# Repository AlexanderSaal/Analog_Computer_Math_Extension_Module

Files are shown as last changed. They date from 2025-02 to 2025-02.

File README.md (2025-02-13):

# Analog Computer: Math Extension Module

This repository provides a math extension module for analog computing applications. The module provides two absolute value functions, two square-root functions, and one logarithmic value function (base $10$ and $e$) of the input. Each output features an indicator LED that provides visual feedback proportional to the output value.

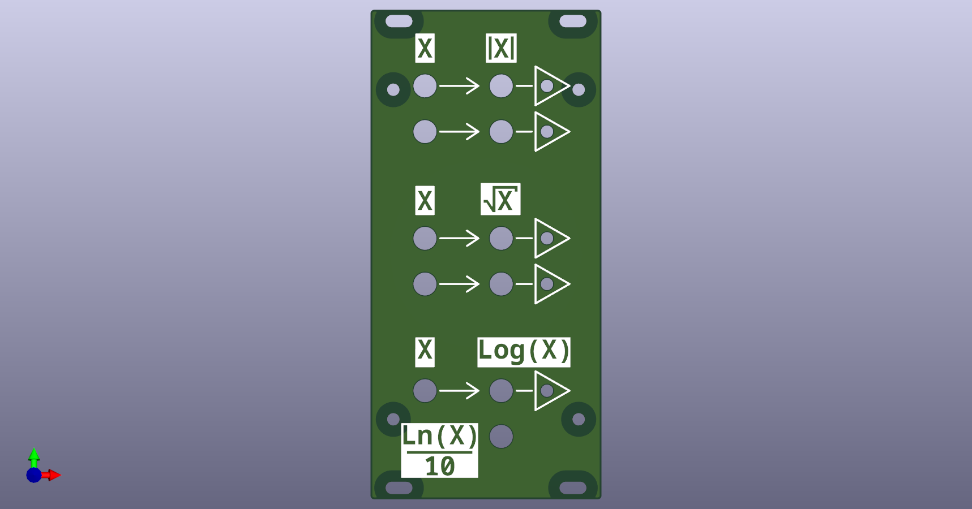
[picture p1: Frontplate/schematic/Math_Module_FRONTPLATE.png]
Front view of the Math Module


## Module Schematic

**<ins>Absolute function(x):</ins>** $x \rightarrow |x|$

The circuit for the absolute value function incorporates two different designs.

The left circuit is based on individual diodes and represents the classical implementation of an absolute value circuit. This circuit follows the design outlined in the document [PRECISION ABSOLUTE VALUE CIRCUITS](https://www.ti.com/lit/pdf/sboa068) from BURR-BROWN/TI.

The right circuit is similar but with one important difference: the diodes are replaced with P-channel MOSFETs on a single substrate. This should ensure thermal coupling and closely specifications of the two MOSFETs.

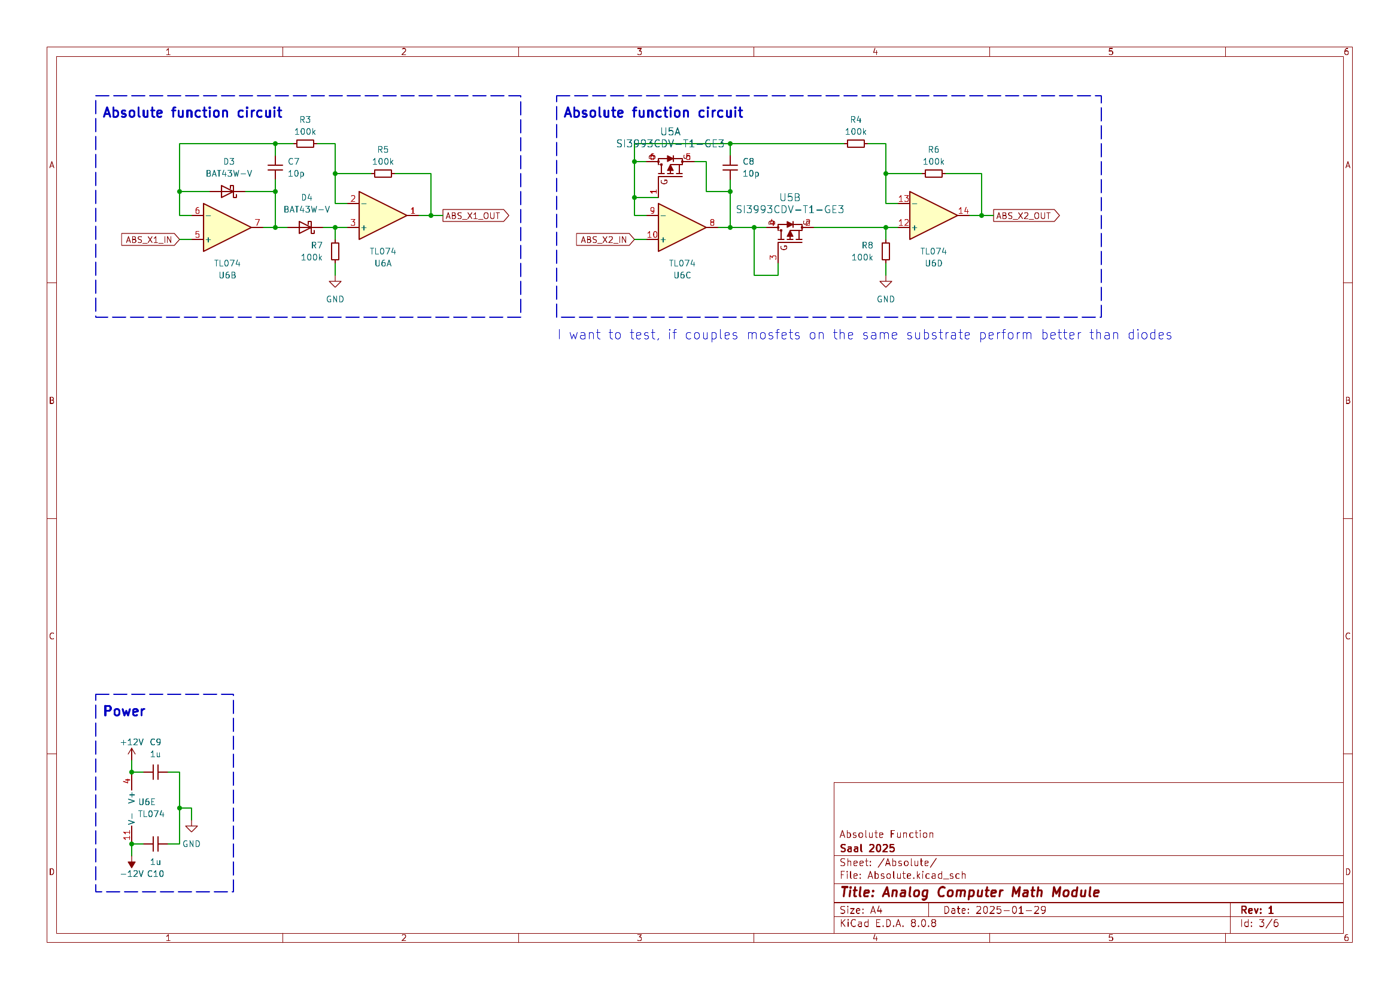
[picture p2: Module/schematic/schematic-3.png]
Schematic of the Absolute function circuit


**<ins>Square-Root function(x):</ins>** $x \rightarrow \sqrt{x}$

The circuit implementation of the square-root function is based on the feedback principle. A multiplier squares the output signal and feeds it back into an open-loop amplifier to yield the inverse function. The diode in the feedback path ensures that only negative values are allowed at the input; otherwise, the output remains close to zero, preventing overload. For ease of use, an inverter is placed before the input, resulting in the overall transfer function of the module:

$$
\begin{align}
  f(x) = \begin{cases}
  \sqrt{x} & \text{if } x > 0 \\
  0 & \text{if } x \le 0
  \end{cases}
\end{align}
$$

This circuit design is based on the schematic and principals presented in the book [Analog and Hybrid Computer Programming](https://www.degruyter.com/document/doi/10.1515/9783110662207/html) by Prof. Dr. Bernd Ulmann and the [book on the THAT Analog Computer](http://www.astro-electronic.de/THAT_Analog_Computer_Book.pdf) by Michael Koch.

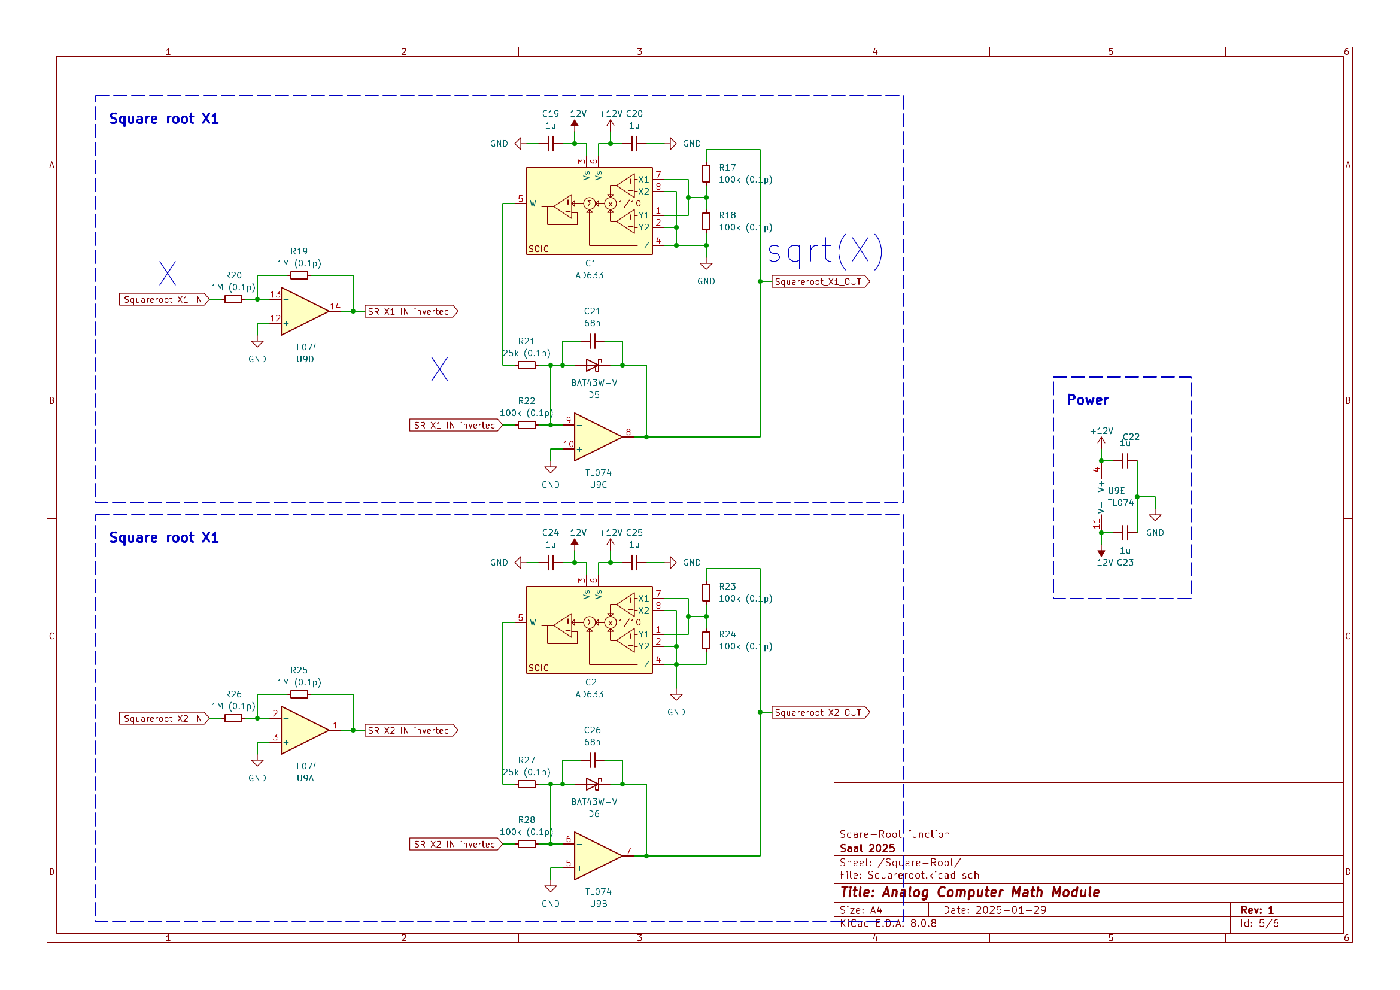
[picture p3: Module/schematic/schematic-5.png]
Schematic of the Square-Root function circuit


**<ins>Logarithmic function(x):</ins>** $x \rightarrow \mathrm{log}_{10}(x)$ and $x \rightarrow \mathrm{log}_{e}(x)$

The logarithm function circuit is based on the [LOG200](https://www.ti.com/product/LOG200) chip from Texas Instruments. The input voltage must be scaled down from $\pm 10 \, V$ to the chip's maximum accepted range of $\pm 5 \, V$. According to the datasheet, $-5V$ falls within the absolute maximum ratings and will not damage the chip.

The transfer function of the LOG200 chip is

$$ V_\mathrm{LOG} = 250 \, mV \cdot \mathrm{log}_{10} \left( \frac{I_1}{I_2} \right) $$

which depends on the ratio of the input currents $I_1$ and $I_2$. The input current $I_2$ is wired to the internal $1 \, \mu A$ precision current source. Accordingly, the input voltage has to be scaled using a precision (0.05\%) $50k\Omega$ resistor to give the appropriate current $I_1$. Since we want to map the output to the full range of our machine unit, $\pm1$ or $\pm 10 \,V$, a "20x" amplifier is placed after the output of the Voltage $V_\mathrm{LOG}$.

With this scaling, the following input-output relationship is achieved:

| Input | Current $I_1$ | Output of LOG200 | Circuit Output |
|---|---|---|---|
|$0.001 \, V$|$0.01 \, \mu A$|$-0.5\,V$ | $-10 \, V$ |
|$0.01 \, V$ |$0.1 \, \mu A$ |$-0.25\,V$ | $-5 \, V$ |
|$0.1 \, V$  |$1 \, \mu A$ |$0\,V$ | $0 \, V$ |
|$1 \, V$ |$10 \, \mu A$  |$0.25\,V$ | $5 \, V$ |
|$10 \, V$ |$100 \, \mu A$ |$0.5\,V$ | $10 \, V$ |

To additionally compute the natural logarithm $\mathrm{log}_e$, we use the relation:

$$ \mathrm{log}_{e}(x) = \frac{\mathrm{log}_{10}(x)}{\mathrm{log}_{10}(e)} = 2.303 \cdot \mathrm{log}_{10}(x) $$

A simple scaling amplifier with a gain of $0.2303x$ is used to provide the output of $\mathrm{log}_e(x) / 10$.

This circuit design and Input/Output scaling are based on the circuit presented in the book [Analog and Hybrid Computer Programming](https://www.degruyter.com/document/doi/10.1515/9783110662207/html) by Prof. Dr. Bernd Ulmann. I took the liberty of replacing the LOG112 with the LOG200 chip and adding the natural logarithm functionality.

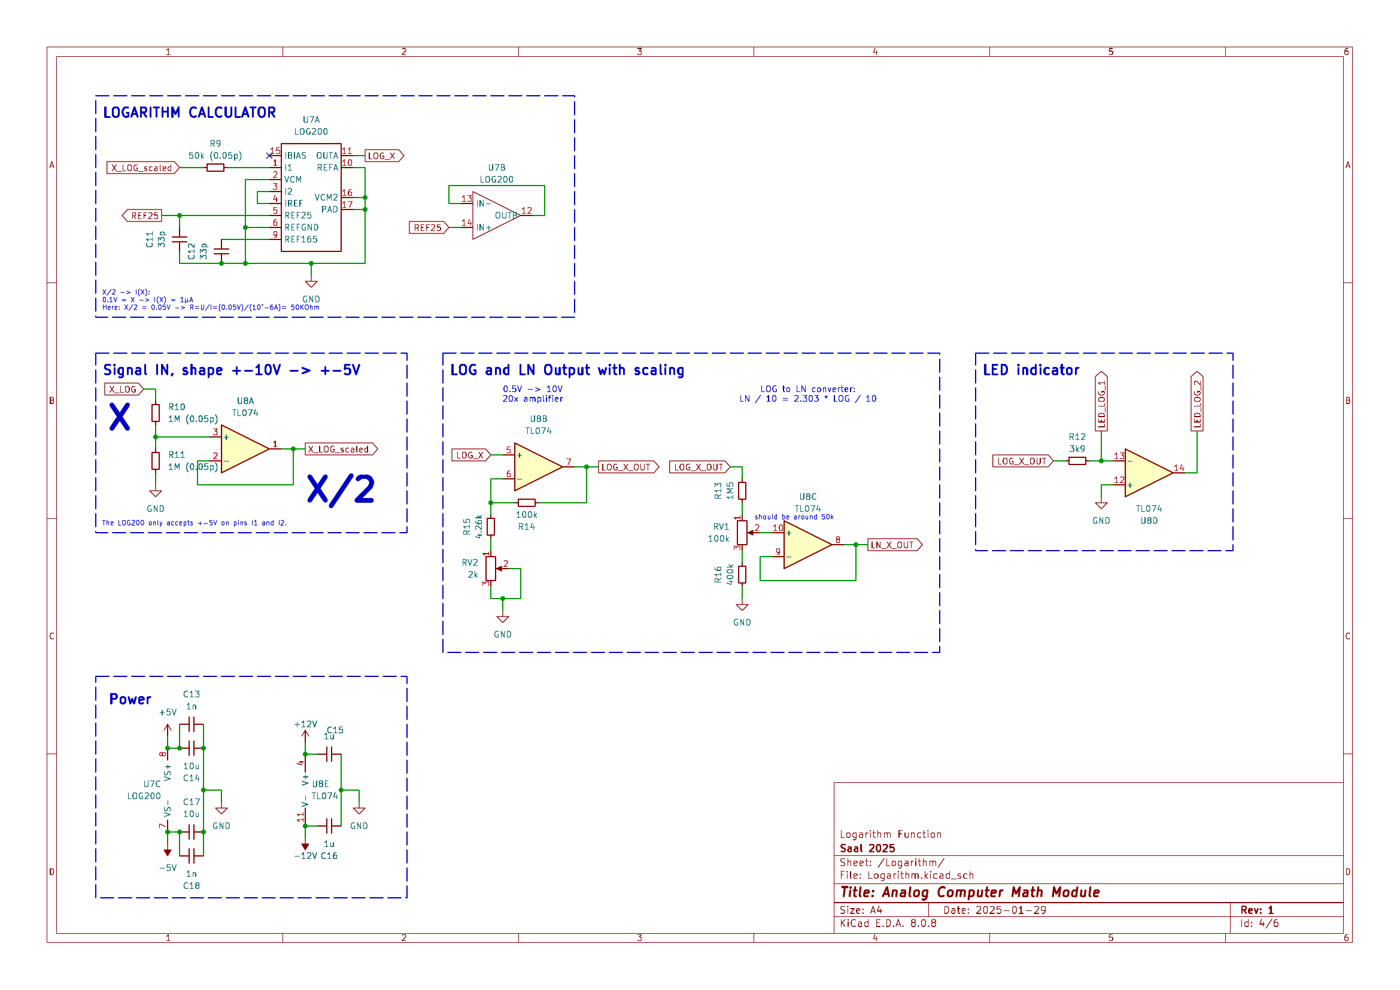
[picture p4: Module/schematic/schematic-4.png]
Schematic of the Logarithm function circuit


## BOM

**<ins>Main Module:</ins>** 

|Reference |Value |Footprint |QUANTITY|
|---|---|---|---|
|C1,C2,C14,C17 |10u |1206 / 3216Metric |4 |
|C3,C5 |0.33u |1206 / 3216Metric |2 |
|C4,C6,C9,C10,C15,C16,C19,C20,C22-C25,C27,C28|1u |1206 / 3216Metric |14 |
|C7,C8 |10p |1206 / 3216Metric |2 |
|C11,C12 |33p |1206 / 3216Metric |2 |
|C13,C18 |1n |1206 / 3216Metric |2 |
|C21,C26 |68p |1206 / 3216Metric |2 |
|D1 |12V_GREEN |1206 / 3216Metric |1 |
|D2 |-12V_RED |1206 / 3216Metric |1 |
|D3-D6 |BAT43W-V |1206 / 3216Metric |4 |
|IC1,IC2 |AD633 |SOIC-8 |2 |
|J1 |Conn_01x23_Pin |PinHeader_1x23_P2.54mm_Vertical |1 |
|J2 |Conn_02x05_Odd_Even|PinHeader_2x05_P2.54mm_Vertical |1 |
|Q1 |PMV250EPEA |SOT-23 |1 |
|Q2 |PMV450ENEA |SOT-23 |1 |
|R1 |11k2 |1206 / 3216Metric |1 |
|R2 |5k6 |1206 / 3216Metric |1 |
|R3-R8,R14 |100k |1206 / 3216Metric |7 |
|R9 |50k (0.05p) |1206 / 3216Metric |1 |
|R10,R11 |1M (0.05p) |1206 / 3216Metric |2 |
|R12,R29-R32 |3k9 |1206 / 3216Metric |5 |
|R13 |1M5 |1206 / 3216Metric |1 |
|R15 |4.26k |1206 / 3216Metric |1 |
|R16 |400k |1206 / 3216Metric |1 |
|R17,R18,R22-R24,R28 |100k (0.1p) |1206 / 3216Metric |6 |
|R19,R20,R25,R26 |1M (0.1p) |1206 / 3216Metric |4 |
|R21,R27 |25k (0.1p) |1206 / 3216Metric |2 |
|RV1 |100k |Potentiometer_Bourns_3296W_Vertical|1 |
|RV2 |2k |Potentiometer_Bourns_3296W_Vertical|1 |
|U1 |MC7805ACTG |TO-220-3_Vertical |1 |
|U2 |MC7905BTG |TO-220-3_Vertical |1 |
|U3,U4 |VCAN16A2 |VCAN16A2-03S-E3-08 |2 |
|U5 |SI3993CDV-T1-GE3 |TSOT-23-6 |1 |
|U6,U8-U10 |TLE2074IDWR |SOIC-14\_3.9x8.7mm\_P1.27mm |4 |
|U7 |LOG200 |VQFN-16 |1 |

**<ins>Middleplate:</ins>**

|Reference |Value |Footprint |QUANTITY|
|---|---|---|---|
|D1-D5 |BI color LED |LED_D3.0mm_FlatTop |5 |
|J1 |Conn_01x23_Pin |PinSocket_1x23_P2.54mm_Vertical |1 |
|U1-U6 |VCAN16A2 |VCAN16A2-03S-E3-08 |6 |

## List of special Components:

- OP-amp: [TLE2074IDWR](https://www.digikey.de/en/products/detail/texas-instruments/TLE2074IDWR/2799317) (Upgrade of the [TL074HIDR](https://www.digikey.de/en/products/detail/texas-instruments/TL074HIDR/13563033))
- logarithmic amplifier: [TL441CN](https://www.digikey.de/de/products/detail/texas-instruments/TL441CN/1675117), [LOG112AID](https://www.digikey.de/de/products/detail/texas-instruments/LOG112AID/486371), [LOG200RGTT](https://www.digikey.de/de/products/detail/texas-instruments/LOG200RGTT/25821029), [LOG200-datasheet](https://www.ti.com/product/LOG200)
- Multiplier: [AD633JRZ](https://www.digikey.de/en/products/detail/analog-devices-inc/AD633JRZ/617831) to [AD835ARZ](https://www.digikey.de/en/products/detail/analog-devices-inc/AD835ARZ-REEL7/621103)
- P-MOSFET: [SSFQ3805](https://www.digikey.de/en/products/detail/good-ark-semiconductor/SSFQ3805/18667583), [SI3993CDV-T1-GE3](https://www.digikey.de/en/products/detail/vishay-siliconix/SI3993CDV-T1-GE3/4876436)
- P-MOSFET (matched pair):[ALD1117SAL](https://www.digikey.de/en/products/detail/advanced-linear-devices-inc/ALD1117SAL/2414325)
- 16-BIT Schottky Barrier Diode Bus-Termination Array: [SN74S1053PWR](https://www.digikey.de/en/products/detail/texas-instruments/SN74S1053PWR/509741)
- 2 PNP (Dual) Matched Pair:[site](https://www.diodes.com/products/discrete-semiconductors/bipolar-transistors/transistor-bjt-master-table/matchedpair/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), [DMMT3906W-7-F](https://www.digikey.de/en/products/detail/diodes-incorporated/DMMT3906W-7-F/717760), [BCM847BS](https://www.digikey.de/en/products/detail/diotec-semiconductor/BCM847BS/22600802)
- +5V Regulator: [MC7805ACTG](https://www.digikey.de/en/products/detail/onsemi/MC7805ACTG/1481210), [MC7805ABTG](https://www.digikey.de/en/products/detail/onsemi/MC7805ABTG/921035)
- -5V Regulator: [MC7905BTG](https://www.digikey.de/en/products/detail/onsemi/MC7905BTG/1481513)

## License

This work is published under the [CERN Open Hardware Licence Version 2 - Strongly Reciprocal](LICENSE)

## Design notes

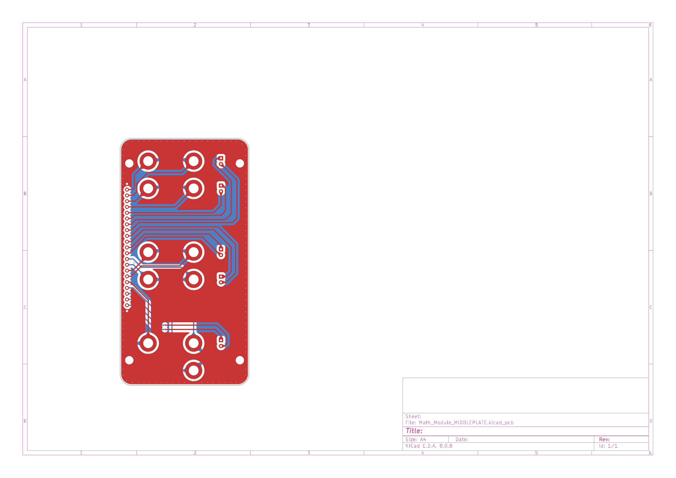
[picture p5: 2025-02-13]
Middleplate/schematic/PCB-1.png

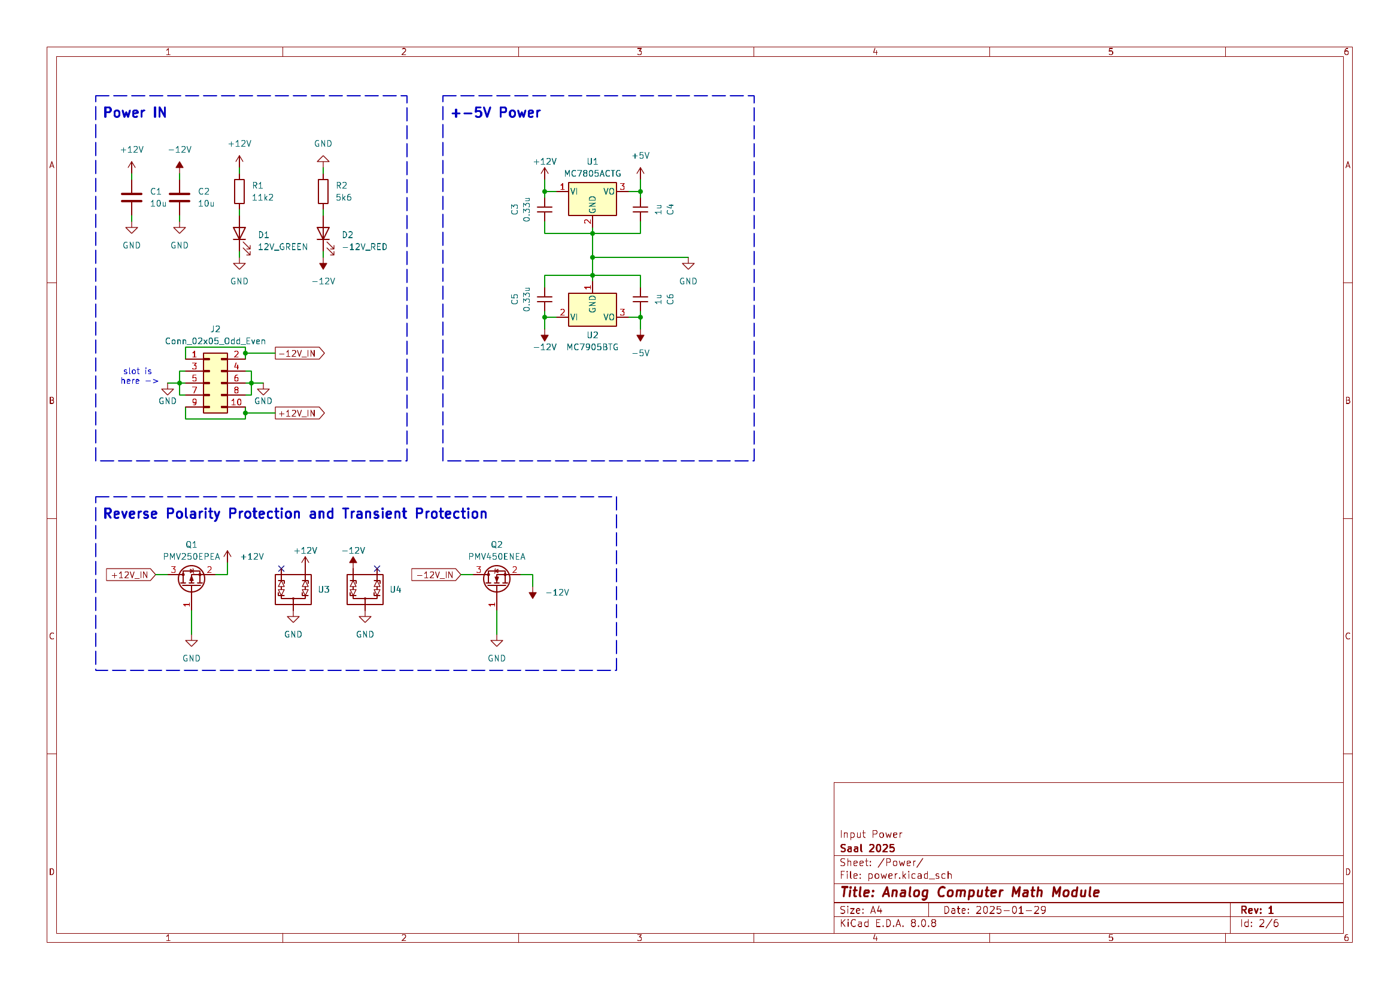
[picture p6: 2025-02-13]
Module/schematic/schematic-2.png

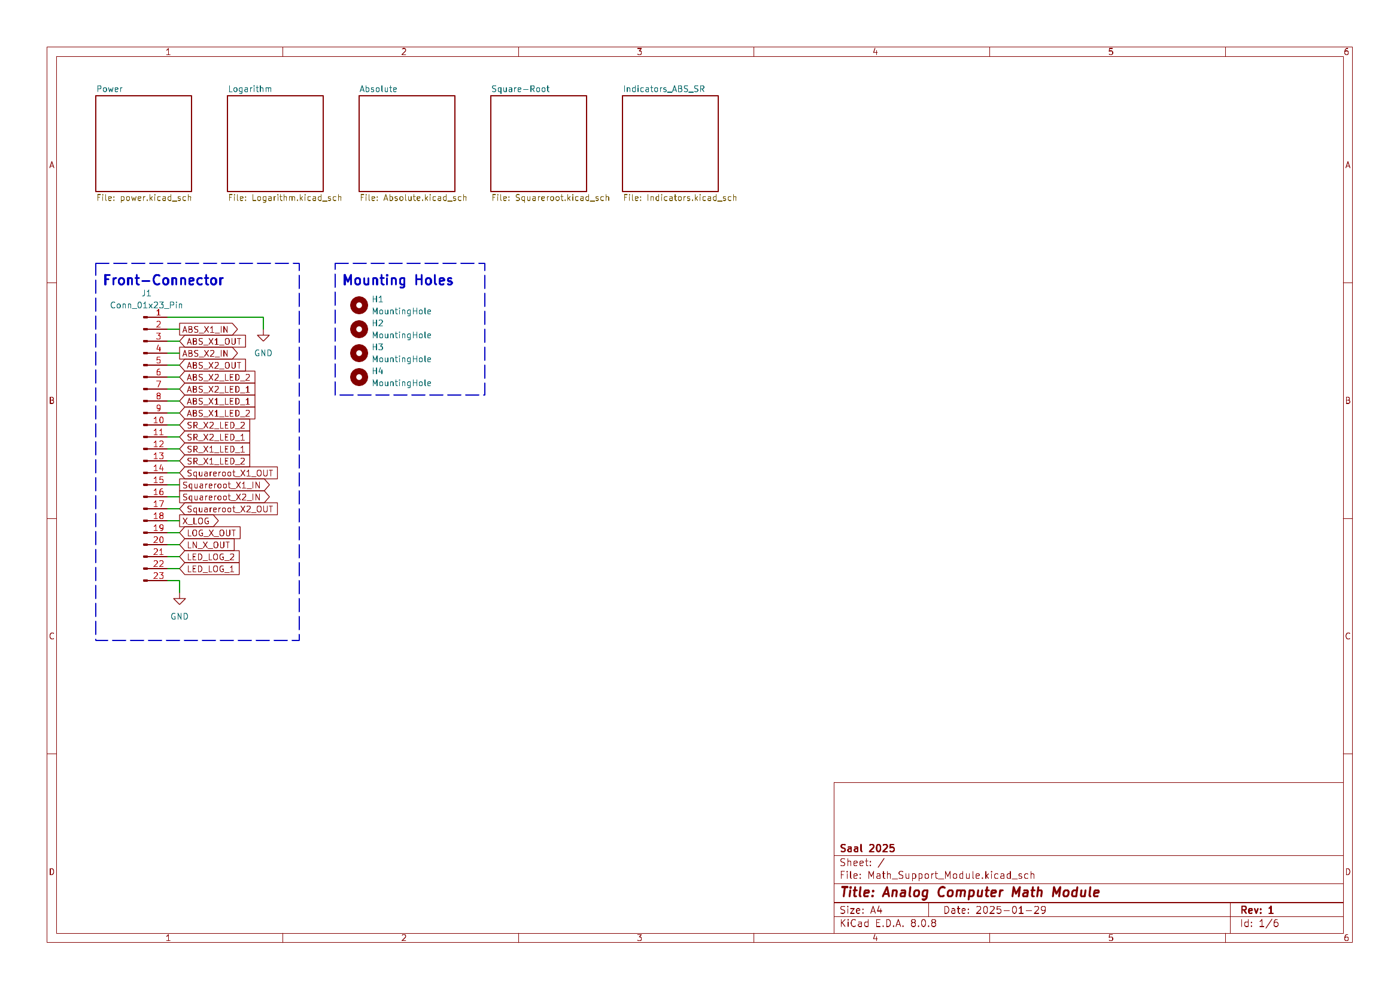
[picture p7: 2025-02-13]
Module/schematic/schematic-1.png

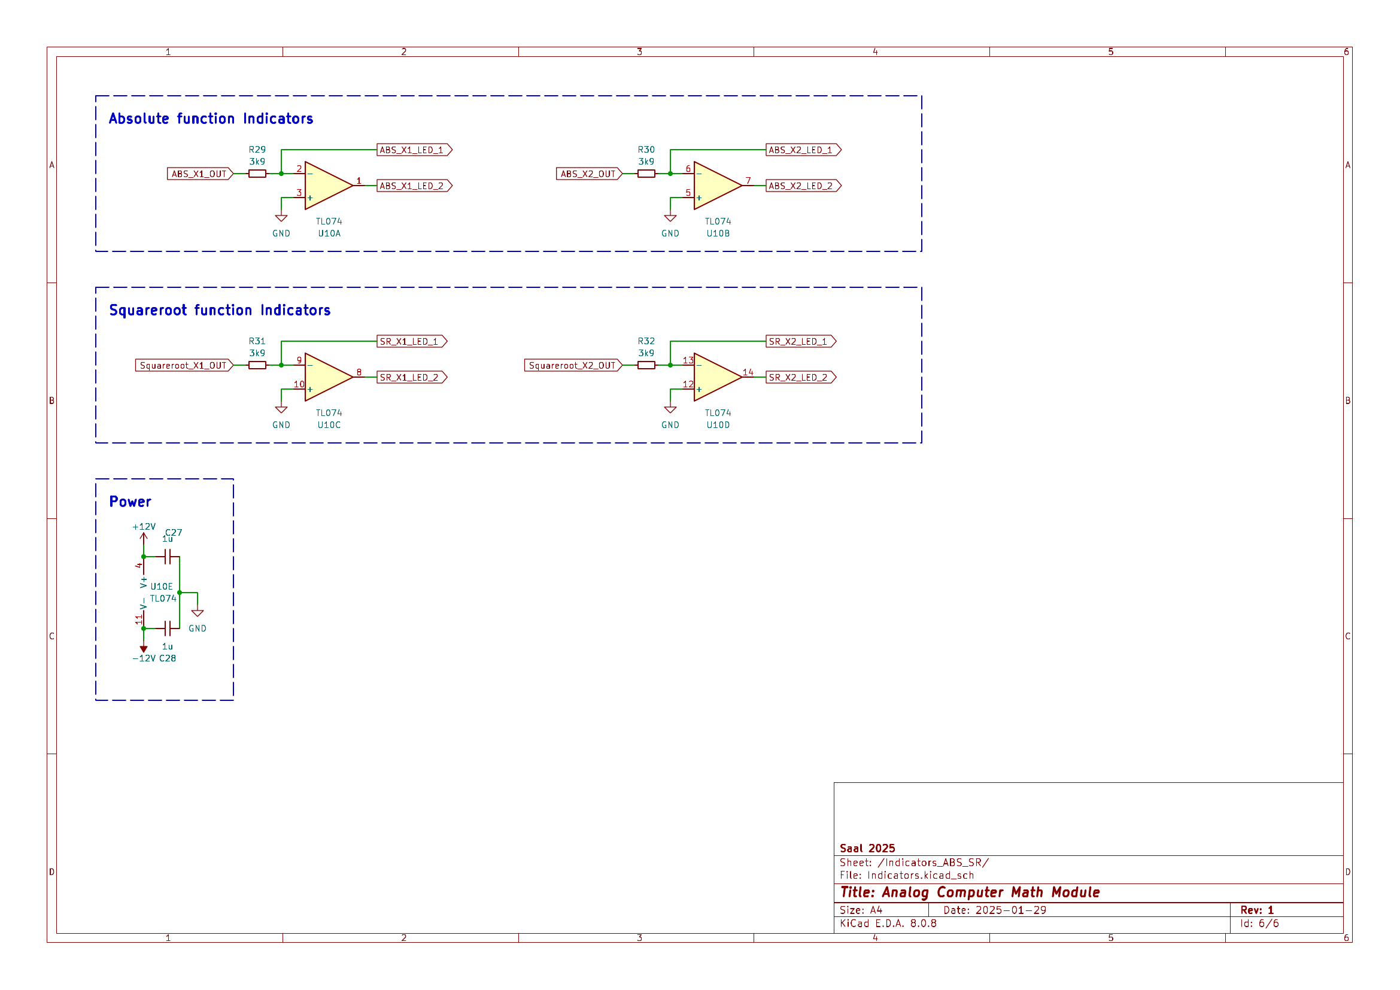
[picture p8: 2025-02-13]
Module/schematic/schematic-6.png

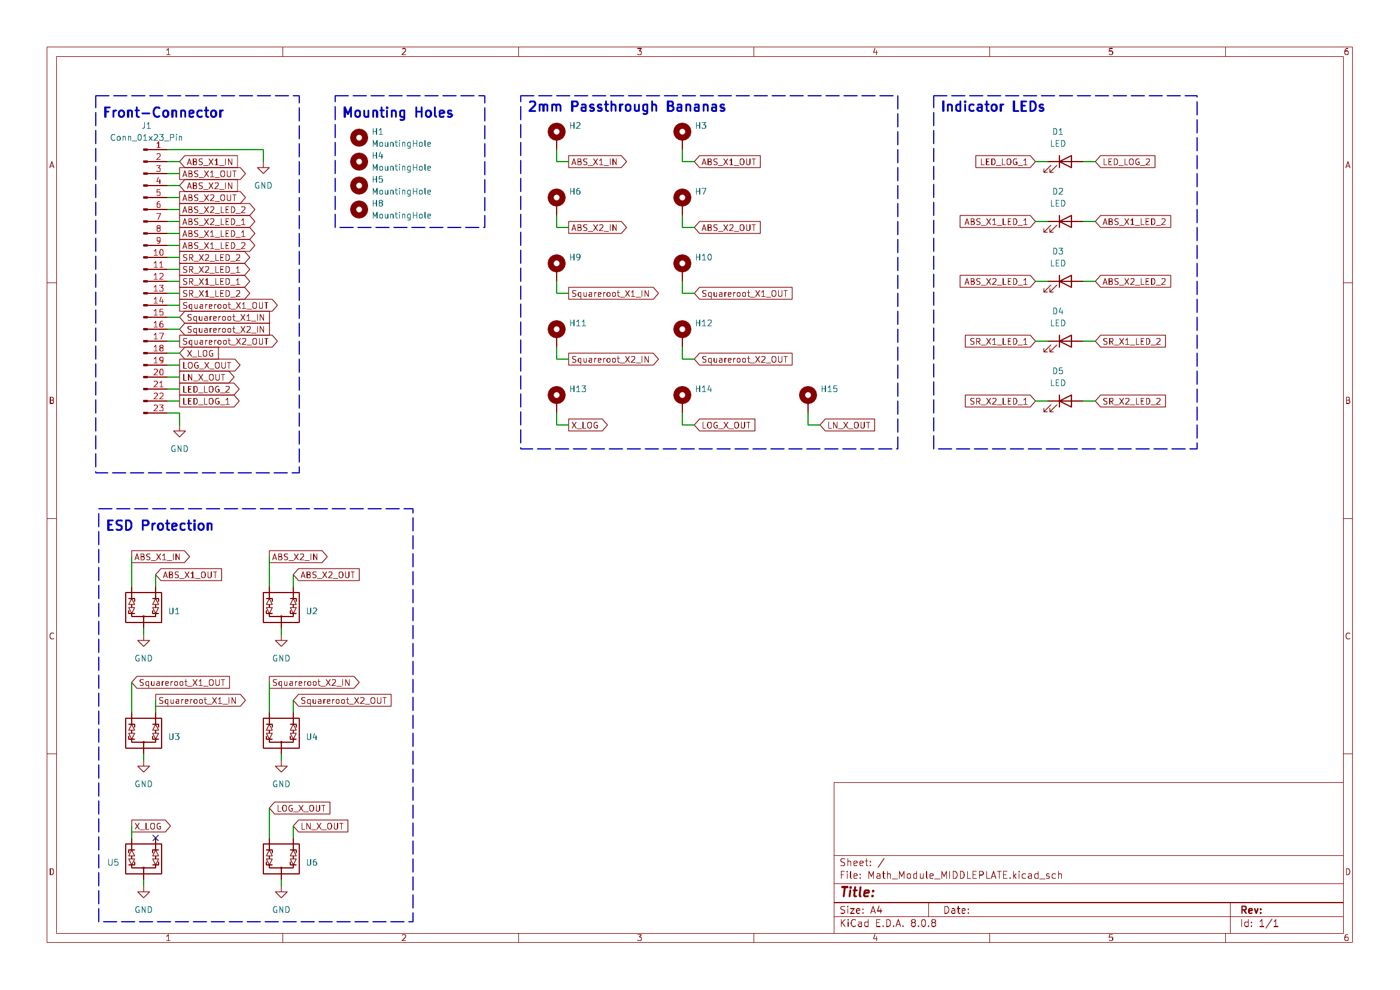
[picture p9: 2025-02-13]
Middleplate/schematic/schematic-1.png

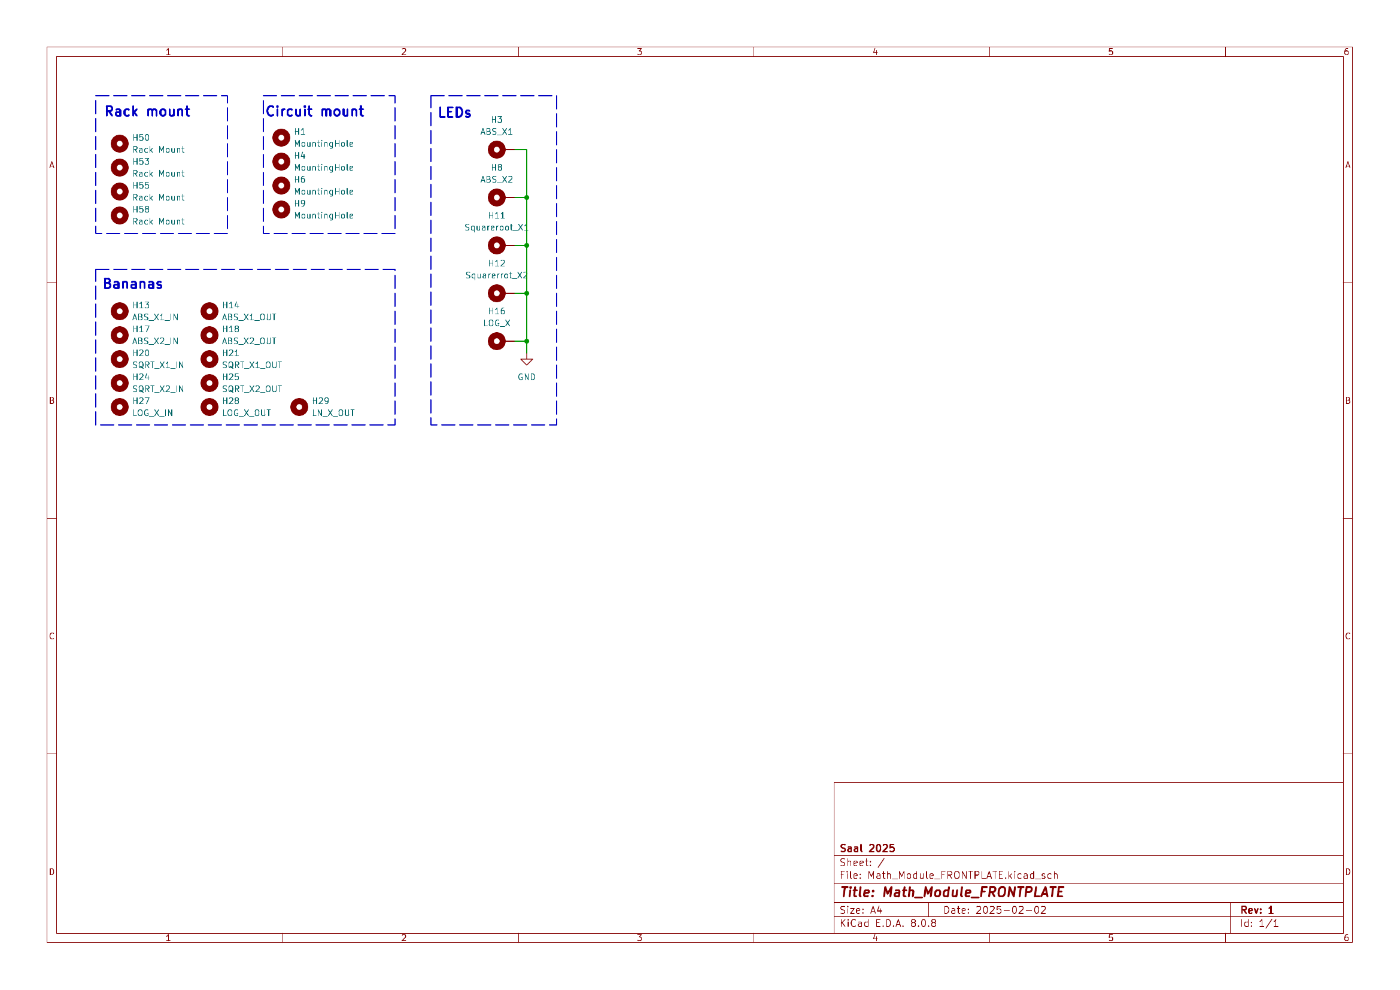
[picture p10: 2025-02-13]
Frontplate/schematic/schematic-1.png

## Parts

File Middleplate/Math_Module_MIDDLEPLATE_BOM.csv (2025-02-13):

Reference | Value | Footprint | QUANTITY
D1-D5 | LED | LED_THT:LED_D3.0mm_FlatTop | 5
J1 | Conn_01x23_Pin | Connector_PinSocket_2.54mm:PinSocket_1x23_P2.54mm_Vertical | 1
U1-U6 | VCAN16A2 | analog_computing:VCAN16A2-03S-E3-08 | 6

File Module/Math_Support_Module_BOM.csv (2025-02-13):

Reference | Value | Footprint | QUANTITY
C1,C2,C14,C17 | 10u | Capacitor_SMD:C_1206_3216Metric_Pad1.33x1.80mm_HandSolder | 4
C3,C5 | 0.33u | Capacitor_SMD:C_1206_3216Metric_Pad1.33x1.80mm_HandSolder | 2
C4,C6,C9,C10,C15,C16,C19,C20,C22-C25,C27,C28 | 1u | Capacitor_SMD:C_1206_3216Metric_Pad1.33x1.80mm_HandSolder | 14
C7,C8 | 10p | Capacitor_SMD:C_1206_3216Metric_Pad1.33x1.80mm_HandSolder | 2
C11,C12 | 33p | Capacitor_SMD:C_1206_3216Metric_Pad1.33x1.80mm_HandSolder | 2
C13,C18 | 1n | Capacitor_SMD:C_1206_3216Metric_Pad1.33x1.80mm_HandSolder | 2
C21,C26 | 68p | Capacitor_SMD:C_1206_3216Metric_Pad1.33x1.80mm_HandSolder | 2
D1 | 12V_GREEN | LED_SMD:LED_1206_3216Metric | 1
D2 | -12V_RED | LED_SMD:LED_1206_3216Metric | 1
D3-D6 | BAT43W-V | Diode_SMD:D_1206_3216Metric_Pad1.42x1.75mm_HandSolder | 4
IC1,IC2 | AD633 | Package_SO:SOIC-8_3.9x4.9mm_P1.27mm | 2
J1 | Conn_01x23_Pin | Connector_PinHeader_2.54mm:PinHeader_1x23_P2.54mm_Vertical | 1
J2 | Conn_02x05_Odd_Even | Connector_PinHeader_2.54mm:PinHeader_2x05_P2.54mm_Vertical | 1
Q1 | PMV250EPEA | Package_TO_SOT_SMD:SOT-23_Handsoldering | 1
Q2 | PMV450ENEA | Package_TO_SOT_SMD:SOT-23_Handsoldering | 1
R1 | 11k2 | Resistor_SMD:R_1206_3216Metric_Pad1.30x1.75mm_HandSolder | 1
R2 | 5k6 | Resistor_SMD:R_1206_3216Metric_Pad1.30x1.75mm_HandSolder | 1
R3-R8,R14 | 100k | Resistor_SMD:R_1206_3216Metric_Pad1.30x1.75mm_HandSolder | 7
R9 | 50k (0.05p) | Resistor_SMD:R_1206_3216Metric_Pad1.30x1.75mm_HandSolder | 1
R10,R11 | 1M (0.05p) | Resistor_SMD:R_1206_3216Metric_Pad1.30x1.75mm_HandSolder | 2
R12,R29-R32 | 3k9 | Resistor_SMD:R_1206_3216Metric_Pad1.30x1.75mm_HandSolder | 5
R13 | 1M5 | Resistor_SMD:R_1206_3216Metric_Pad1.30x1.75mm_HandSolder | 1
R15 | 4.26k | Resistor_SMD:R_1206_3216Metric_Pad1.30x1.75mm_HandSolder | 1
R16 | 400k | Resistor_SMD:R_1206_3216Metric_Pad1.30x1.75mm_HandSolder | 1
R17,R18,R22-R24,R28 | 100k (0.1p) | Resistor_SMD:R_1206_3216Metric_Pad1.30x1.75mm_HandSolder | 6
R19,R20,R25,R26 | 1M (0.1p) | Resistor_SMD:R_1206_3216Metric_Pad1.30x1.75mm_HandSolder | 4
R21,R27 | 25k (0.1p) | Resistor_SMD:R_1206_3216Metric_Pad1.30x1.75mm_HandSolder | 2
RV1 | 100k | Potentiometer_THT:Potentiometer_Bourns_3296W_Vertical | 1
RV2 | 2k | Potentiometer_THT:Potentiometer_Bourns_3296W_Vertical | 1
U1 | MC7805ACTG | Package_TO_SOT_THT:TO-220-3_Vertical | 1
U2 | MC7905BTG | Package_TO_SOT_THT:TO-220-3_Vertical | 1
U3,U4 | VCAN16A2 | analog_computing:VCAN16A2-03S-E3-08 | 2
U5 | SI3993CDV-T1-GE3 | Package_TO_SOT_SMD:TSOT-23-6_HandSoldering | 1
U6,U8-U10 | TL074 | Package_SO:SOIC-14_3.9x8.7mm_P1.27mm | 4
U7 | LOG200 | Package_DFN_QFN:VQFN-16-1EP_3x3mm_P0.5mm_EP1.6x1.6mm_ThermalVias | 1

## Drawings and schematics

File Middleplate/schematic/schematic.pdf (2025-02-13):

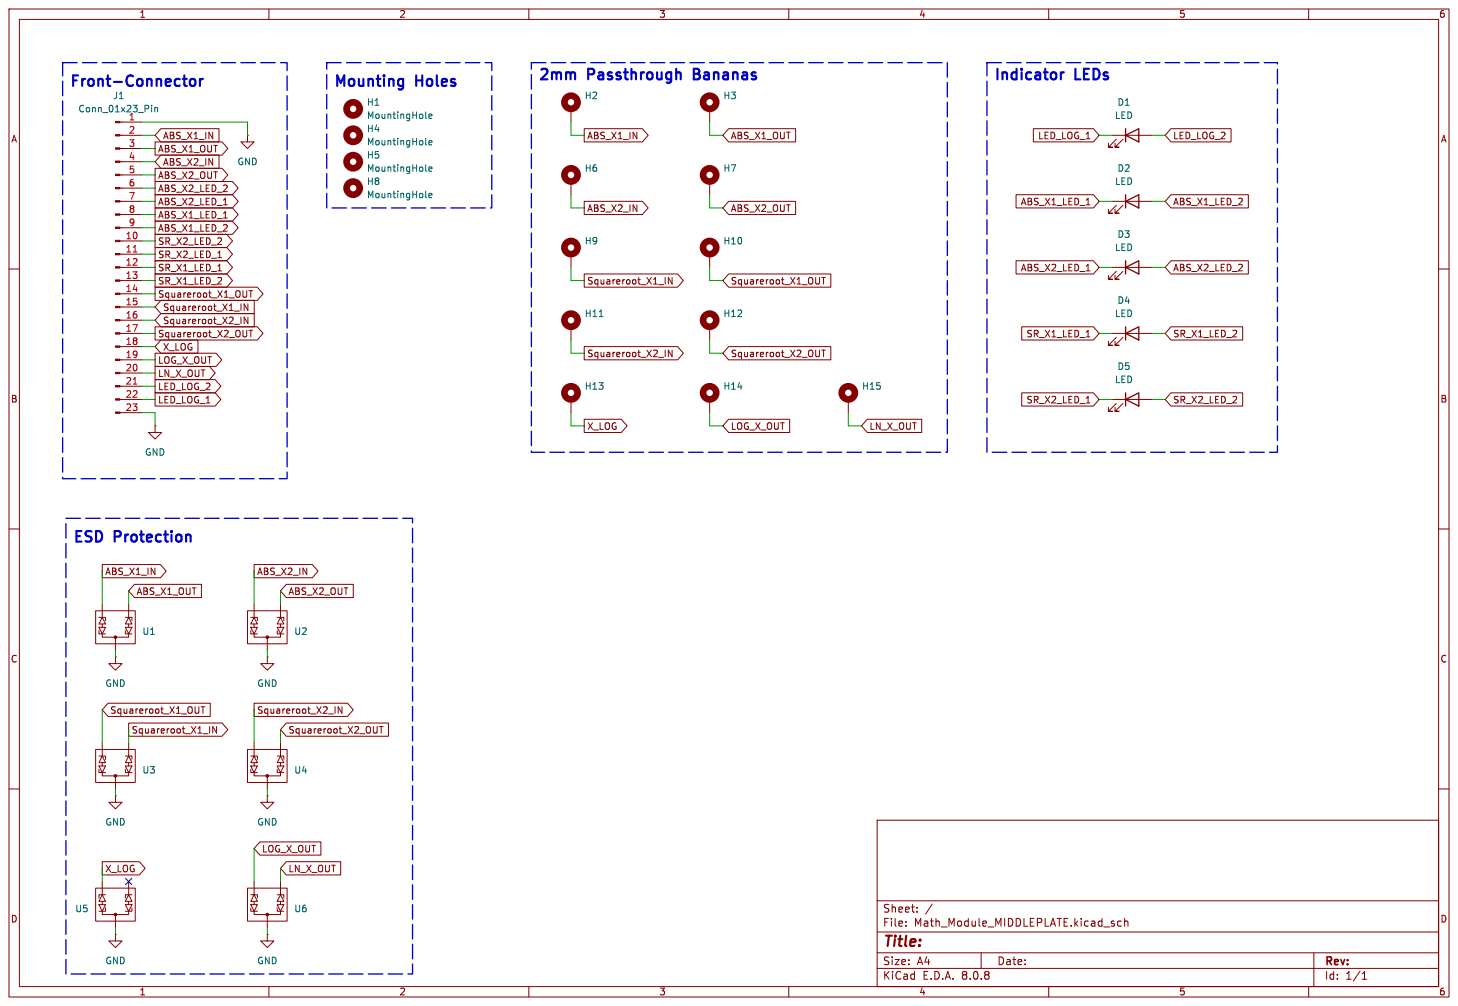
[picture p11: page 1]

Id: 1/1 Title: File: Math_Module_MIDDLEPLATE.kicad_sch Sheet: /

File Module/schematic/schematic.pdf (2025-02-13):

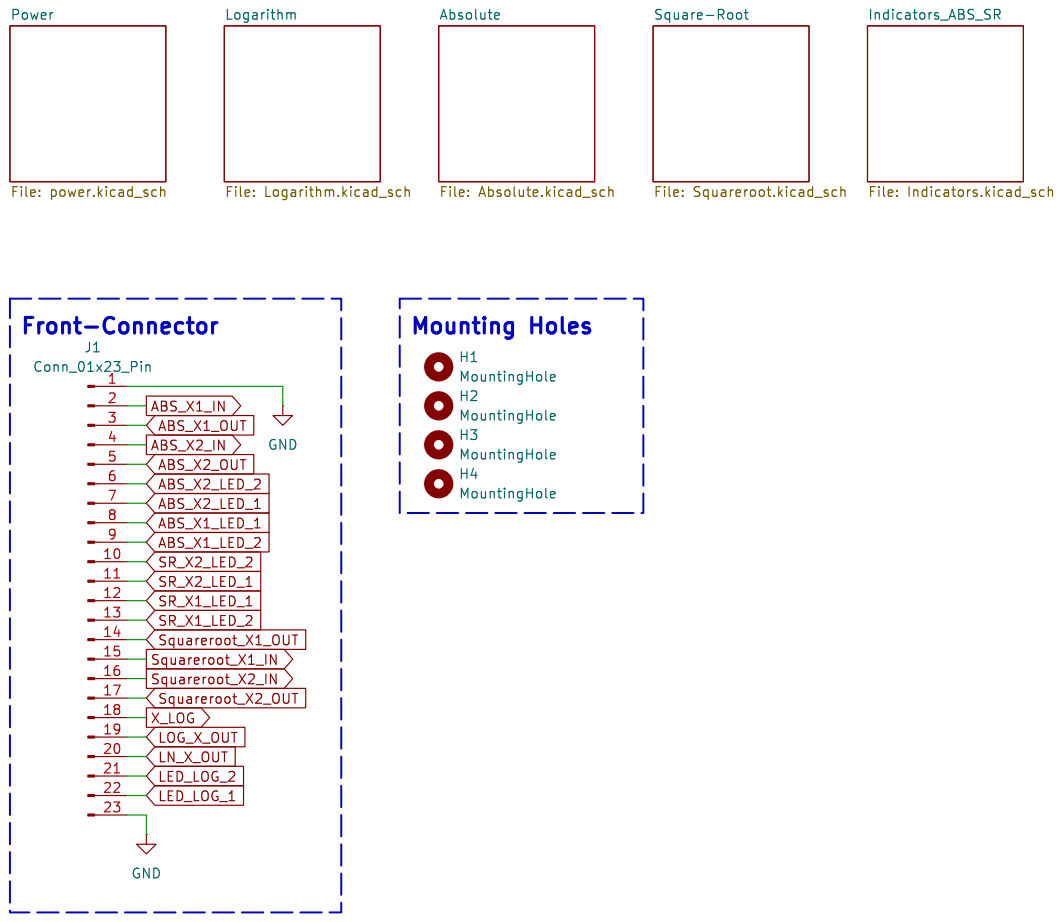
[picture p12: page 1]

File: Indicators.kicad_sch Square-Root File: Squareroot.kicad_sch Absolute File: Absolute.kicad_sch Power File: power.kicad_sch

Id: 1/6 Title: Analog Computer Math Module

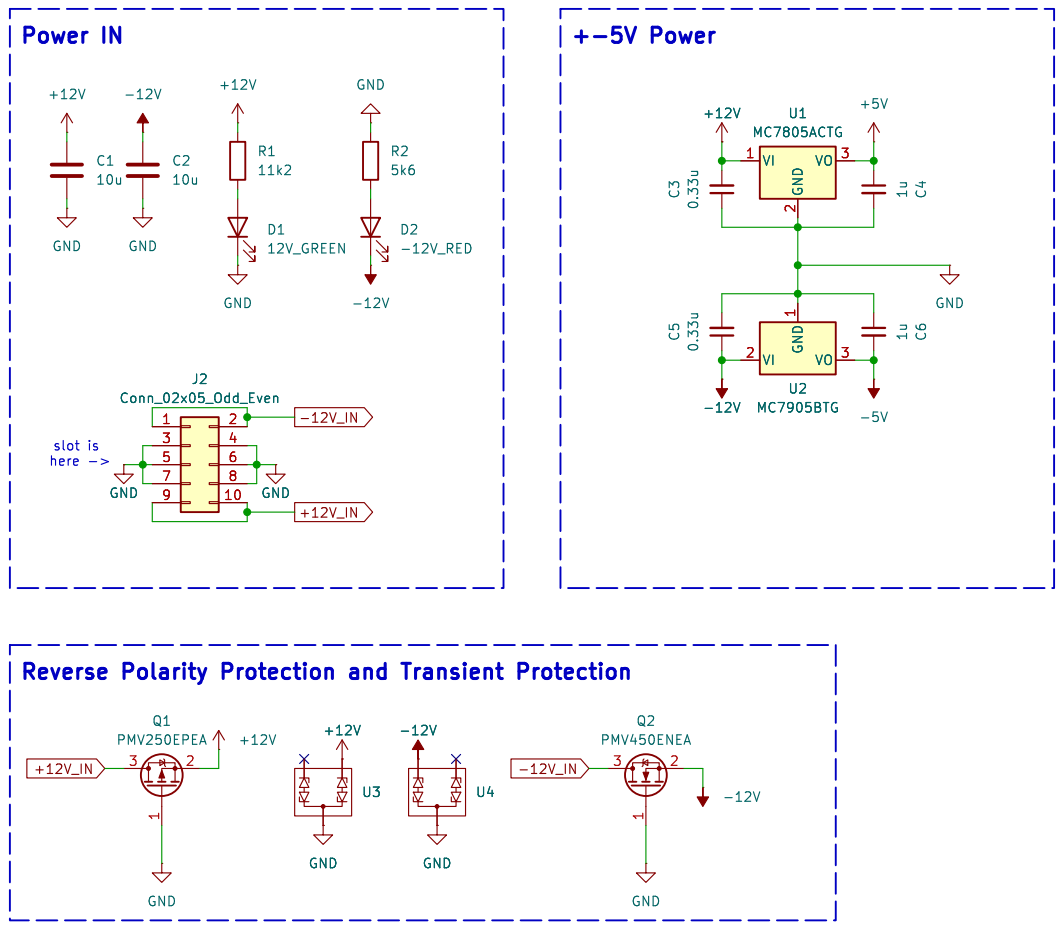
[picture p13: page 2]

File: power.kicad_sch Sheet: /Power/ Saal 2025

Id: 2/6 Title: Analog Computer Math Module

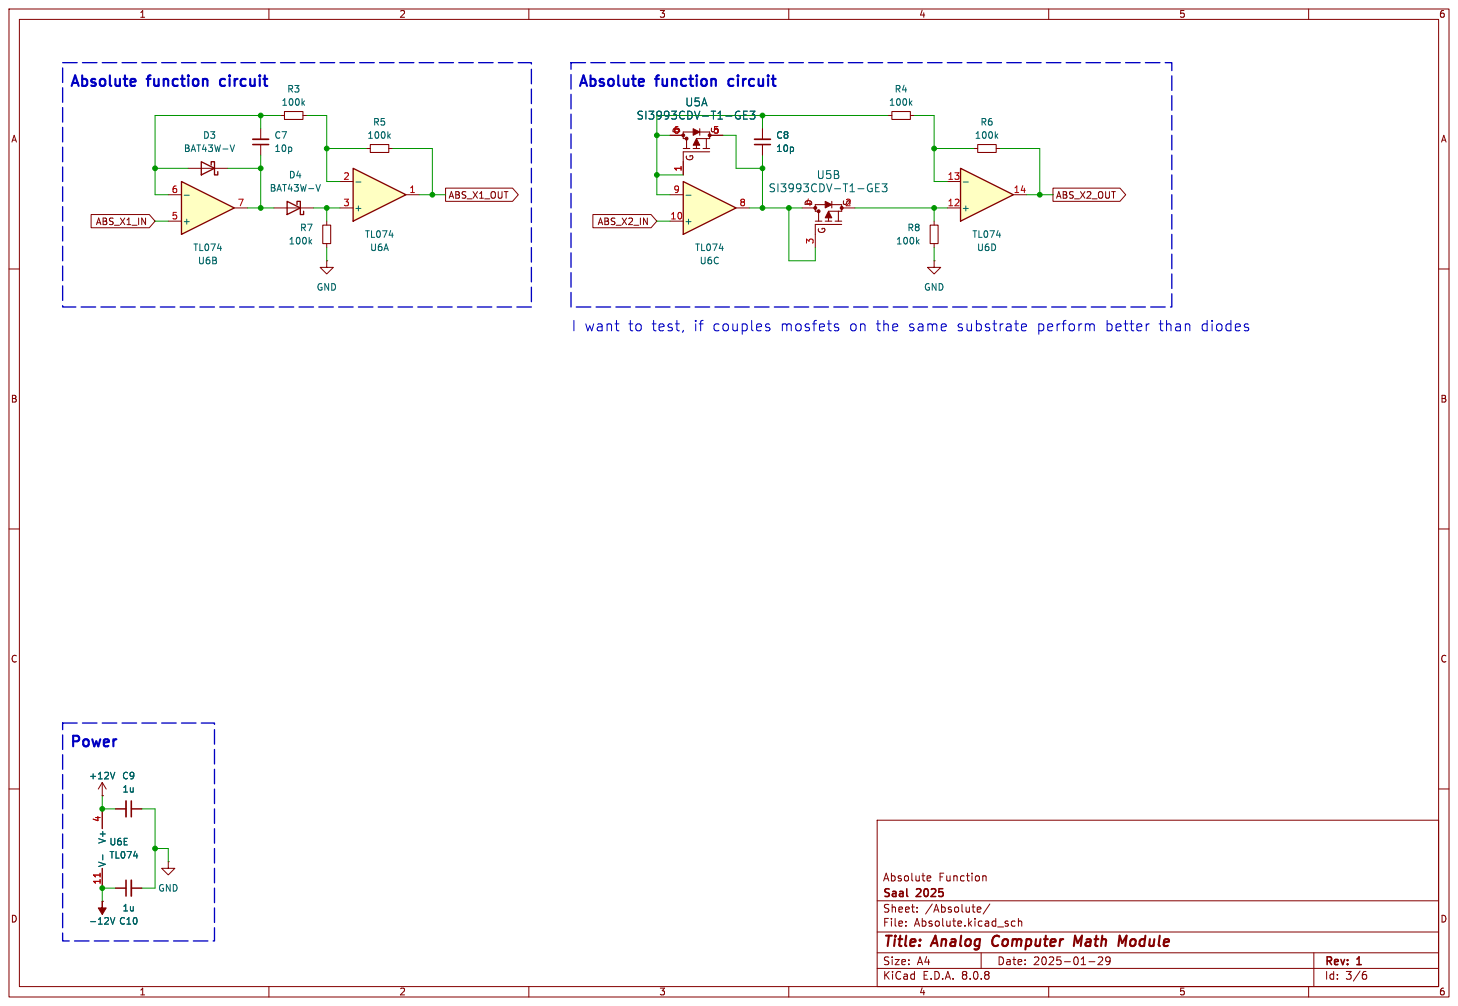
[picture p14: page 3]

Id: 3/6 Title: Analog Computer Math Module

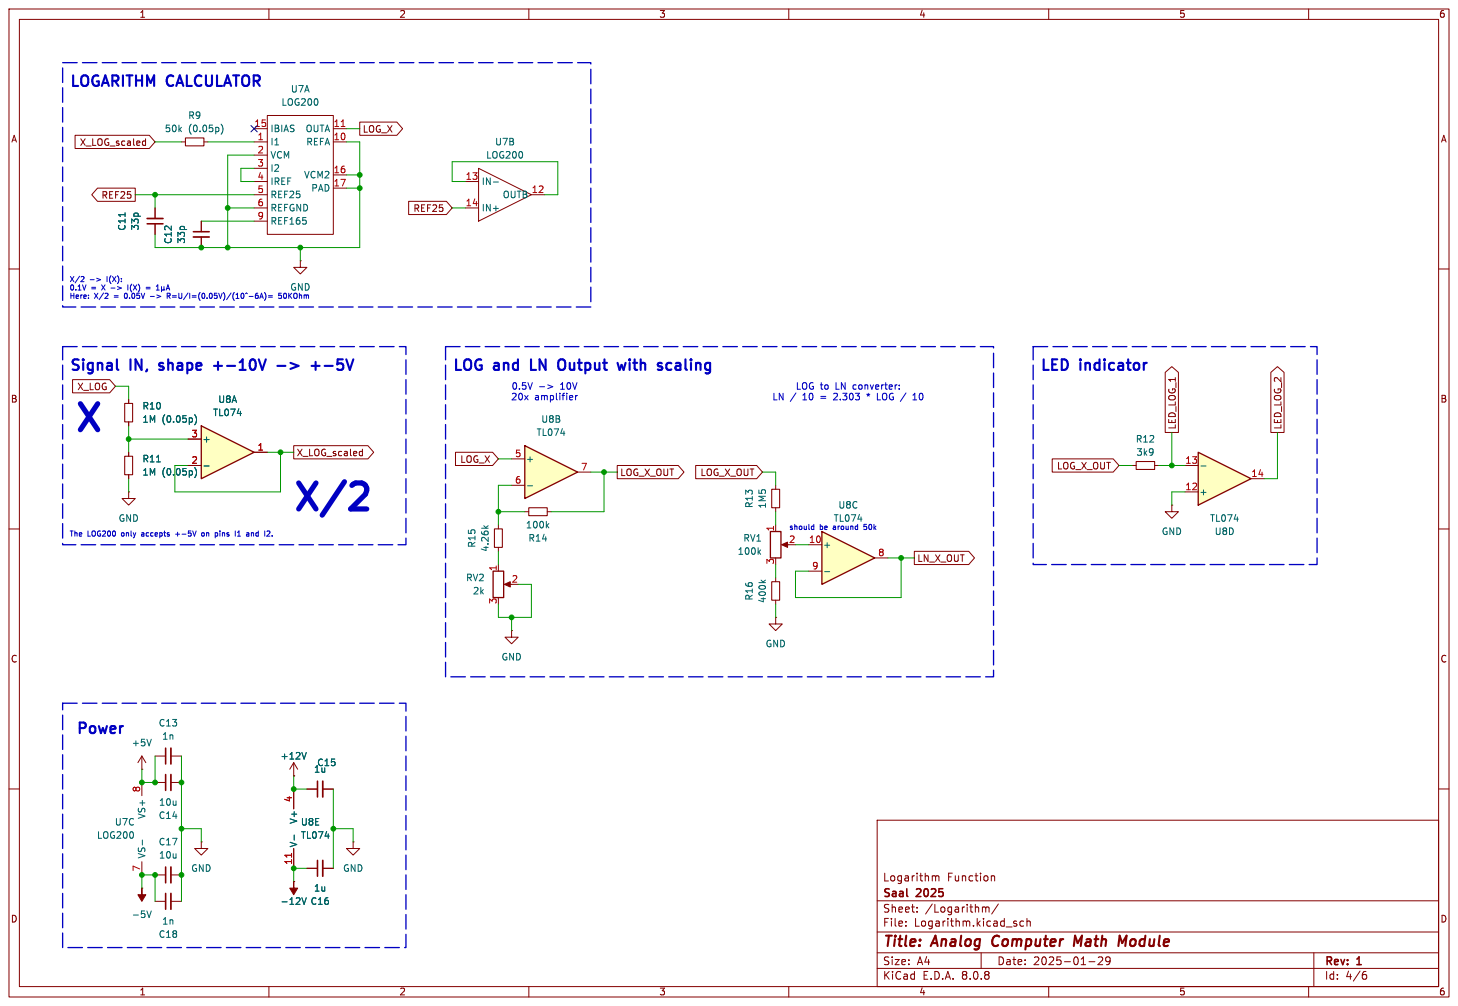
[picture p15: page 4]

should be around 50k LOG to LN converter: LN / 10 = 2.303 * LOG / 10 X
LN_X_OUT X_LOG

File: Logarithm.kicad_sch Sheet: /Logarithm/ Saal 2025

Id: 4/6 Title: Analog Computer Math Module

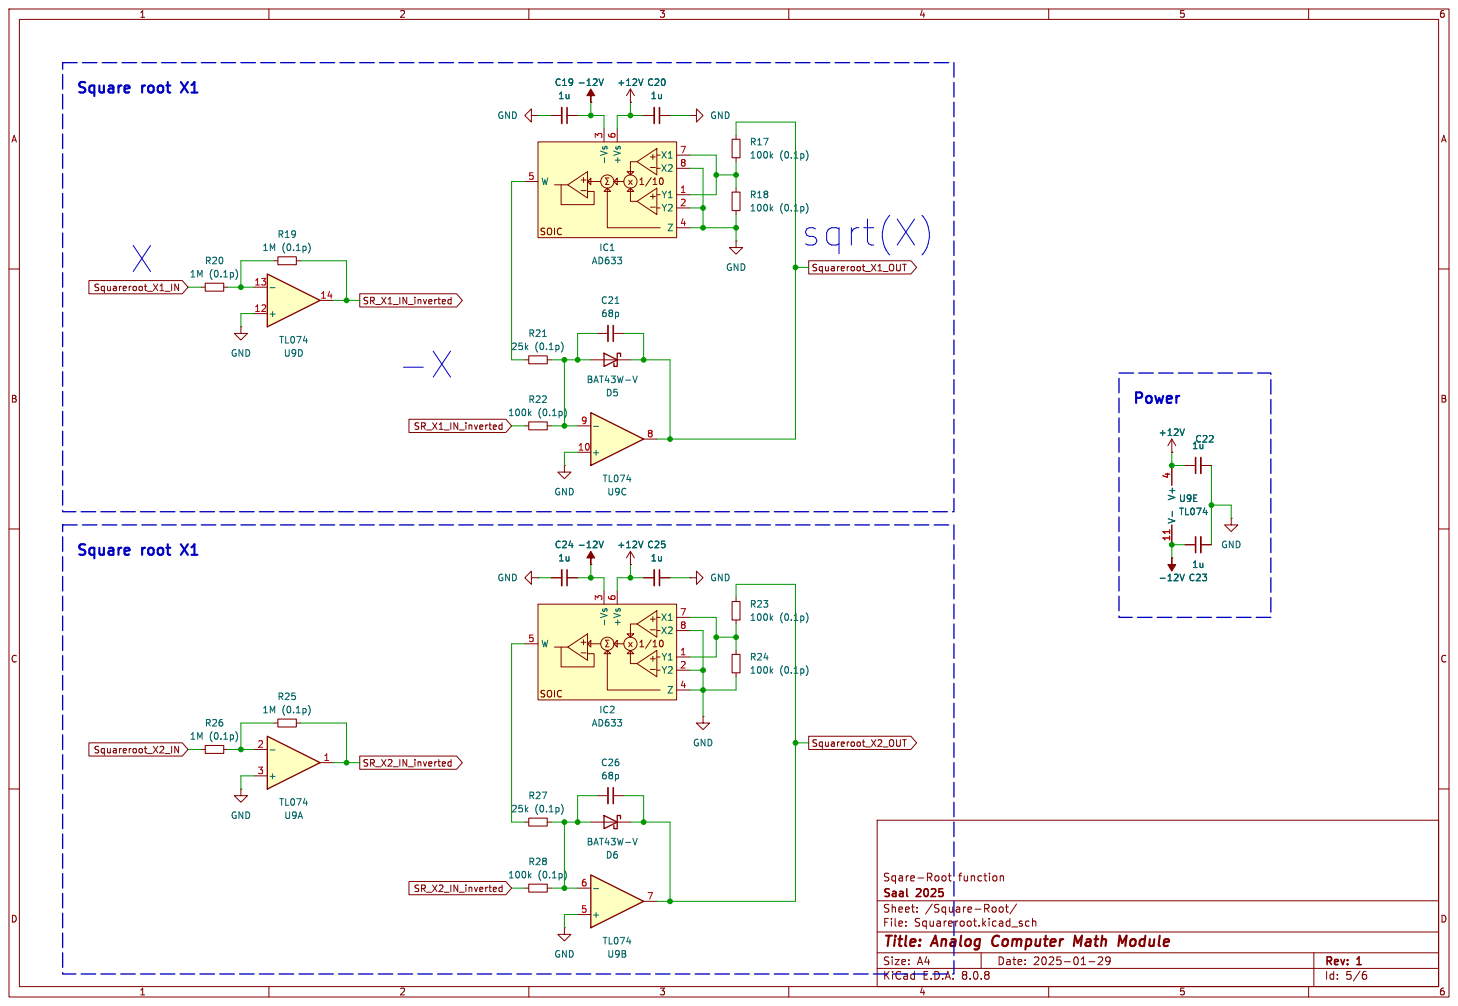
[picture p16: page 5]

Id: 5/6 Title: Analog Computer Math Module

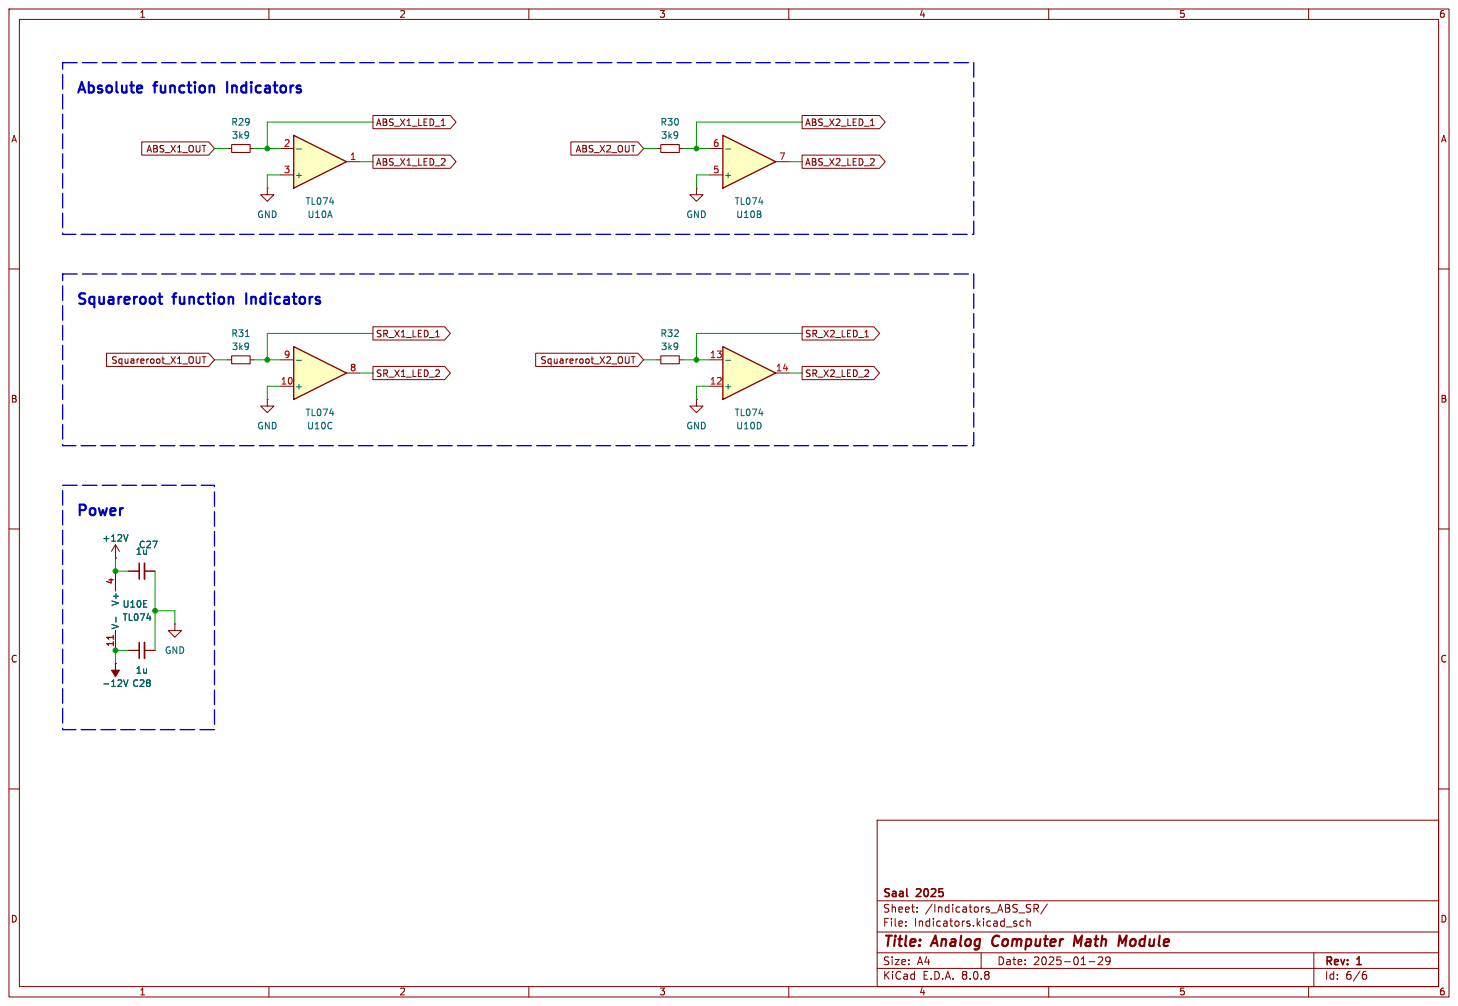
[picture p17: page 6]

File: Indicators.kicad_sch Sheet: /Indicators_ABS_SR/ Saal 2025

Id: 6/6 Title: Analog Computer Math Module

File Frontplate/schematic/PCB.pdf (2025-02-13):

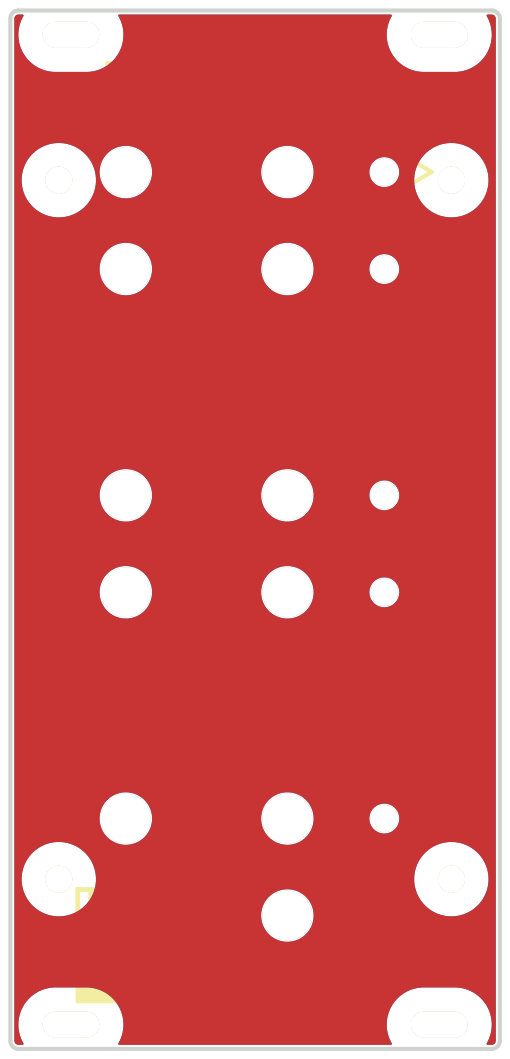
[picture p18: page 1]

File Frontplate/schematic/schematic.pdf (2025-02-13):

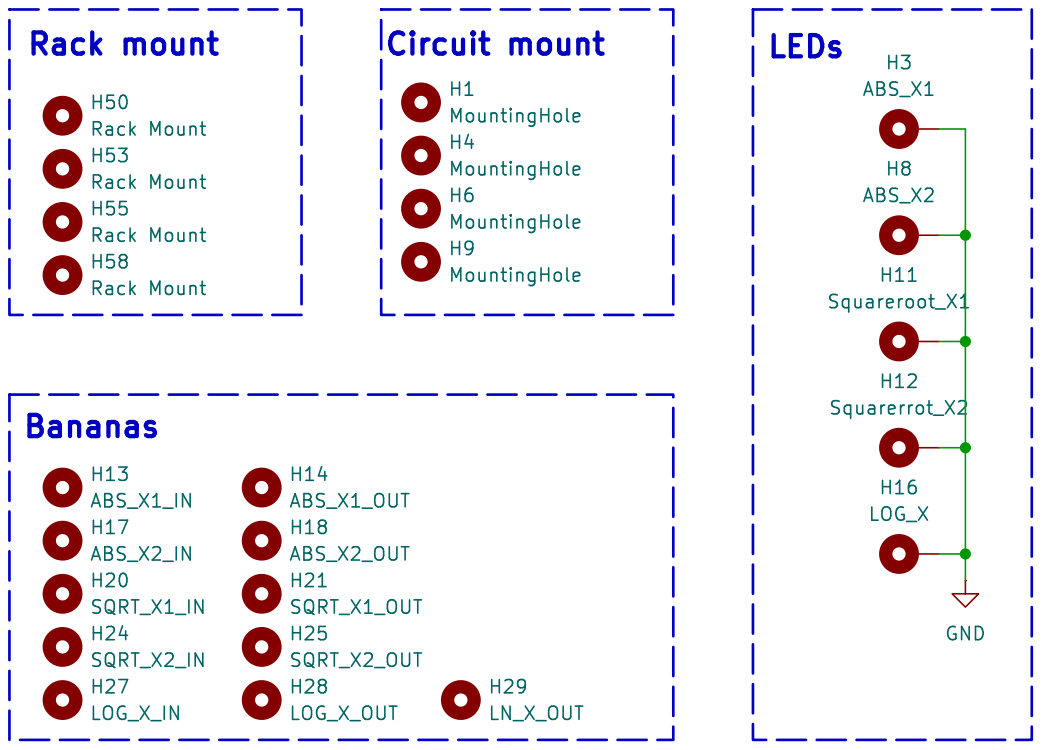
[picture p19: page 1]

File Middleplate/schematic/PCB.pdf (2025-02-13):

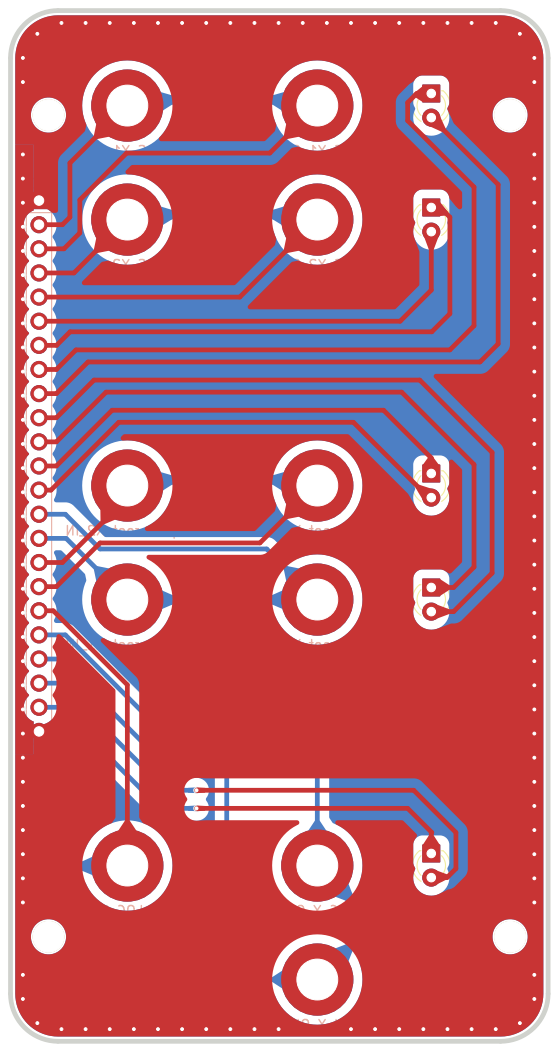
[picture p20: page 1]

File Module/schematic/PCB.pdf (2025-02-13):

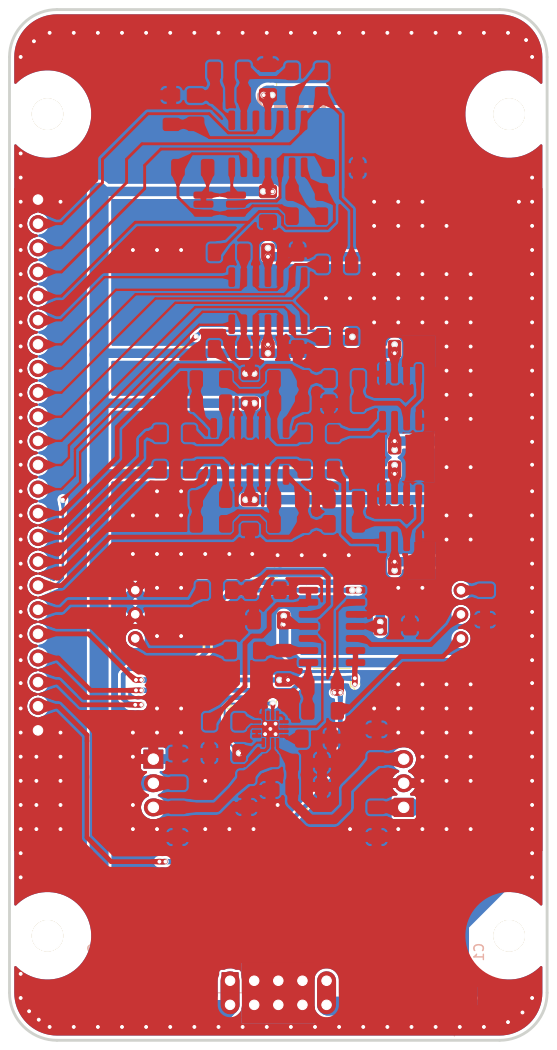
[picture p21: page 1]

Id: 1/1 Title: Analog Computer Math Module

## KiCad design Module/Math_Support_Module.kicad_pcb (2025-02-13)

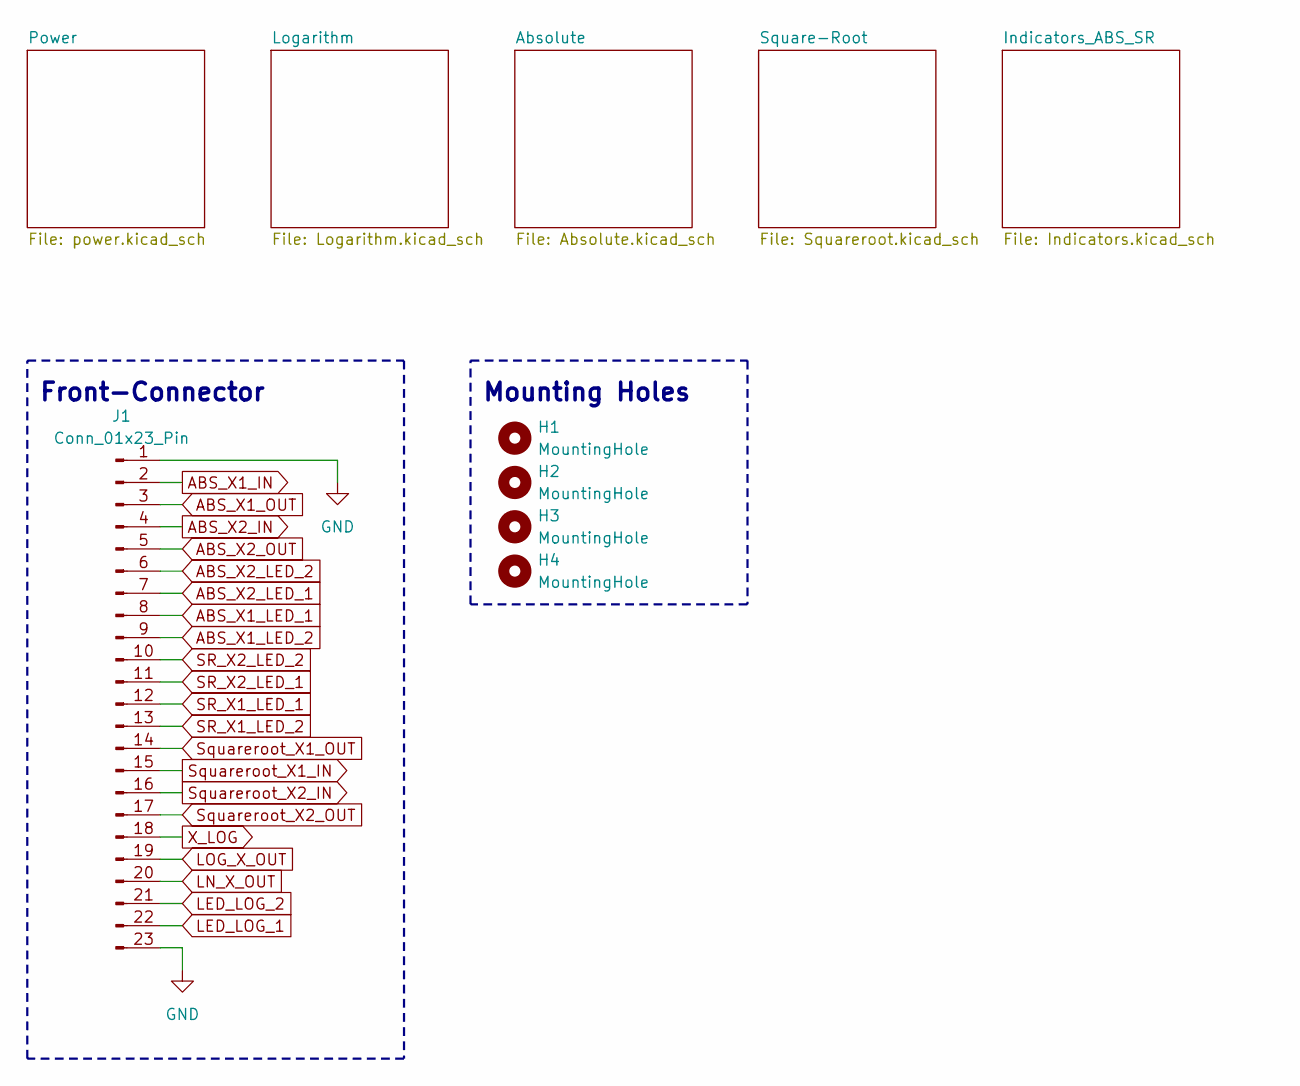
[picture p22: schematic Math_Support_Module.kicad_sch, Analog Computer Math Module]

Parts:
H1, H2, H3, H4: MountingHole; MountingHole_3.2mm_M3_DIN965
J1: Conn_01x23_Pin; PinHeader_1x23_P2.54mm_Vertical

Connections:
ABS_X1_IN: J1.2; also elsewhere on the board
ABS_X1_LED_1: J1.8; also elsewhere on the board
ABS_X1_LED_2: J1.9; also elsewhere on the board
ABS_X1_OUT: J1.3; also elsewhere on the board
ABS_X2_IN: J1.4; also elsewhere on the board
ABS_X2_LED_1: J1.7; also elsewhere on the board
ABS_X2_LED_2: J1.6; also elsewhere on the board
ABS_X2_OUT: J1.5; also elsewhere on the board
GND: J1.1, J1.23; also elsewhere on the board
LED_LOG_1: J1.22; also elsewhere on the board
LED_LOG_2: J1.21; also elsewhere on the board
LN_X_OUT: J1.20; also elsewhere on the board
LOG_X_OUT: J1.19; also elsewhere on the board
SR_X1_LED_1: J1.12; also elsewhere on the board
SR_X1_LED_2: J1.13; also elsewhere on the board
SR_X2_LED_1: J1.11; also elsewhere on the board
SR_X2_LED_2: J1.10; also elsewhere on the board
Squareroot_X1_IN: J1.15; also elsewhere on the board
Squareroot_X1_OUT: J1.14; also elsewhere on the board
Squareroot_X2_IN: J1.16; also elsewhere on the board
Squareroot_X2_OUT: J1.17; also elsewhere on the board
X_LOG: J1.18; also elsewhere on the board

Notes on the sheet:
Mounting Holes
Front-Connector

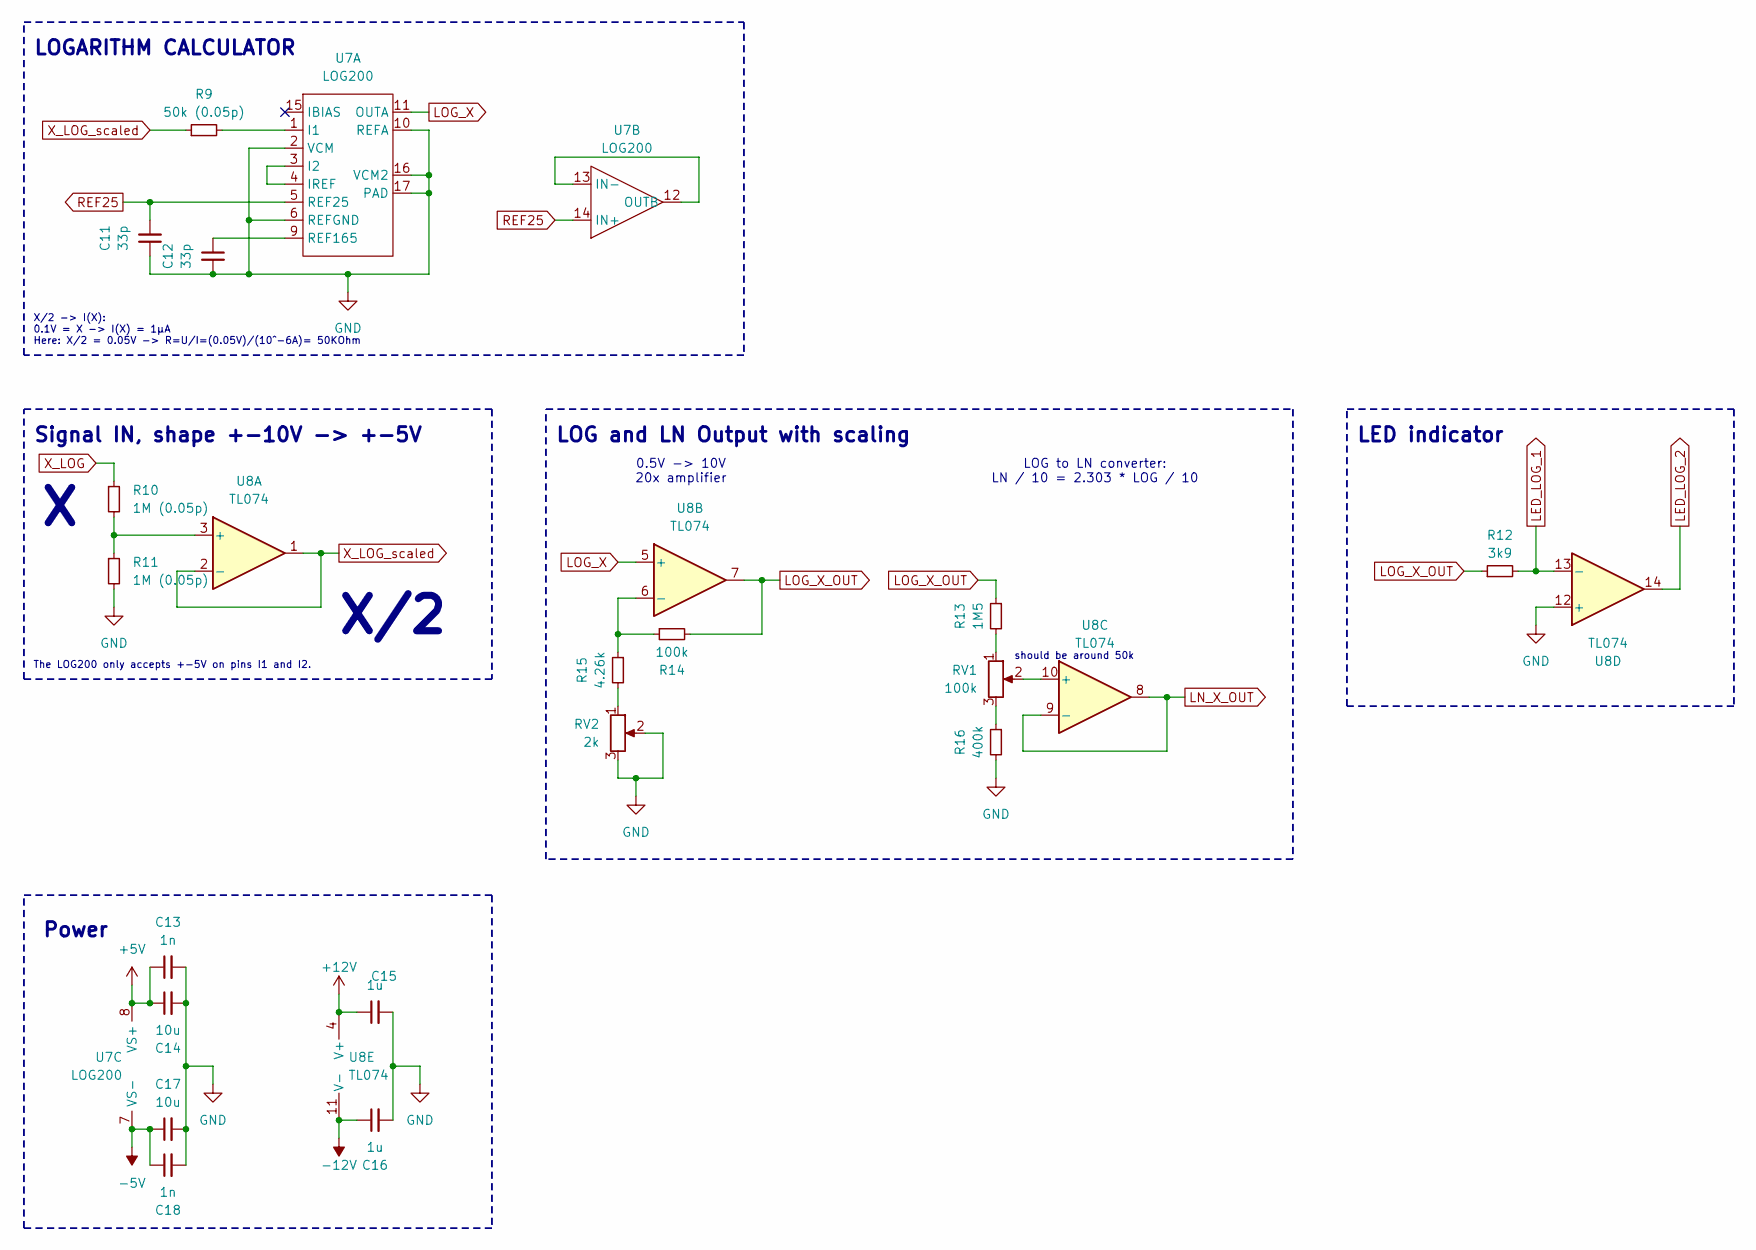
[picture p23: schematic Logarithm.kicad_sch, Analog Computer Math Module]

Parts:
C11, C12: 33p; C_1206_3216Metric_Pad1.33x1.80mm_HandSolder
C13, C18: 1n; C_1206_3216Metric_Pad1.33x1.80mm_HandSolder
C14, C17: 10u; C_1206_3216Metric_Pad1.33x1.80mm_HandSolder
C15, C16: 1u; C_1206_3216Metric_Pad1.33x1.80mm_HandSolder
R9: 50k (0.05p); R_1206_3216Metric_Pad1.30x1.75mm_HandSolder
R10, R11: 1M (0.05p); R_1206_3216Metric_Pad1.30x1.75mm_HandSolder
R12: 3k9; R_1206_3216Metric_Pad1.30x1.75mm_HandSolder
R13: 1M5; R_1206_3216Metric_Pad1.30x1.75mm_HandSolder
R14: 100k; R_1206_3216Metric_Pad1.30x1.75mm_HandSolder
R15: 4.26k; R_1206_3216Metric_Pad1.30x1.75mm_HandSolder
R16: 400k; R_1206_3216Metric_Pad1.30x1.75mm_HandSolder
RV1: 100k; Potentiometer_Bourns_3296W_Vertical
RV2: 2k; Potentiometer_Bourns_3296W_Vertical
U7: LOG200; VQFN-16-1EP_3x3mm_P0.5mm_EP1.6x1.6mm_ThermalVias
U8: TL074; SOIC-14_3.9x8.7mm_P1.27mm

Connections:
+5V: C13.1, C14.1, U7.8 (VS+); also elsewhere on the board
+12V: C15.1, U8.4 (V+); also elsewhere on the board
-5V: C17.1, C18.1, U7.7 (VS-); also elsewhere on the board
-12V: C16.1, U8.11 (V-); also elsewhere on the board
GND: C11.1, C12.2, C13.2, C14.2, C15.2, C16.2, C17.2, C18.2, R11.2, R16.2, RV2.2, RV2.3, U7.2 (VCM), U7.6 (REFGND), U7.10 (REFA), U7.16 (VCM2), U7.17 (PAD), U8.12 (+); also elsewhere on the board
LED_LOG_1: R12.2, U8.13 (-); also elsewhere on the board
LED_LOG_2: U8.14; also elsewhere on the board
LN_X_OUT: U8.8, U8.9 (-); also elsewhere on the board
LOG_X: U7.11 (OUTA), U8.5 (+)
LOG_X_OUT: R12.1, R13.1, R14.2, U8.7; also elsewhere on the board
unnamed: R13.2, RV1.1
unnamed: R15.2, RV2.1
unnamed: R16.1, RV1.3
unnamed: R9.2, U7.1 (I1)
unnamed: U7.3 (I2), U7.4 (IREF)
unnamed: C12.1, U7.9 (REF165)
unnamed: U7.12 (OUTB), U7.13 (IN-)
unnamed: R10.2, R11.1, U8.3 (+)
unnamed: R14.1, R15.1, U8.6 (-)
unnamed: RV1.2, U8.10 (+)
REF25: C11.2, U7.5 (REF25), U7.14 (IN+)
X_LOG: R10.1; also elsewhere on the board
X_LOG_scaled: R9.1, U8.1, U8.2 (-)

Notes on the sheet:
Power
X/2 -> I(X): 0.1V = X -> I(X) = 1µA Here: X/2 = 0.05V -> R=U/I=(0.05V)/(10^-6A)= 50KOhm
LED indicator
Signal IN, shape +-10V -> +-5V
LOG to LN converter: LN / 10 = 2.303 * LOG / 10
The LOG200 only accepts +-5V on pins I1 and I2.
X/2
0.5V -> 10V 20x amplifier
should be around 50k
LOGARITHM CALCULATOR
LOG and LN Output with scaling

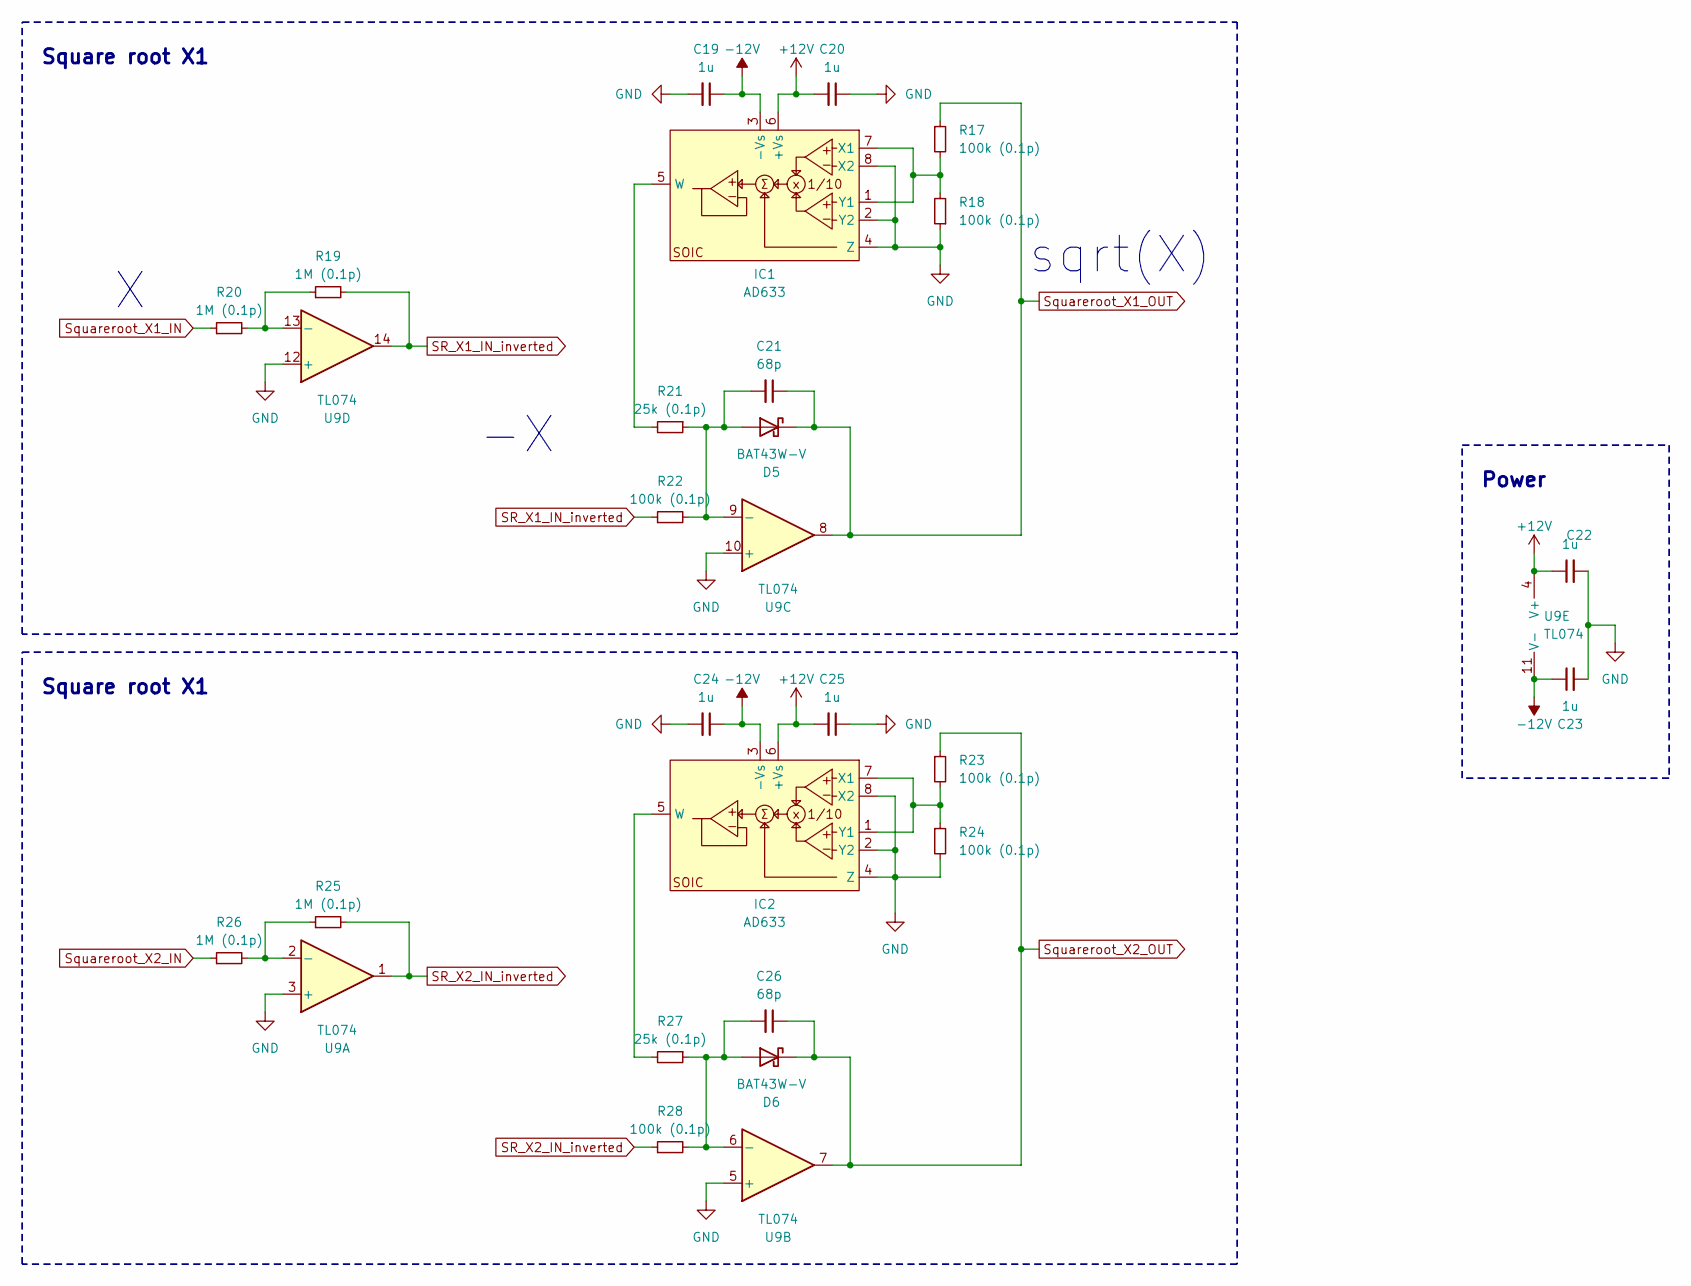
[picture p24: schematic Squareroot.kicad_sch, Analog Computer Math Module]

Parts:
C19, C20, C22, C23, C24, C25: 1u; C_1206_3216Metric_Pad1.33x1.80mm_HandSolder
C21, C26: 68p; C_1206_3216Metric_Pad1.33x1.80mm_HandSolder
D5, D6: BAT43W-V; D_1206_3216Metric_Pad1.42x1.75mm_HandSolder
IC1, IC2: AD633; SOIC-8_3.9x4.9mm_P1.27mm
R17, R18, R22, R23, R24, R28: 100k (0.1p); R_1206_3216Metric_Pad1.30x1.75mm_HandSolder
R19, R20, R25, R26: 1M (0.1p); R_1206_3216Metric_Pad1.30x1.75mm_HandSolder
R21, R27: 25k (0.1p); R_1206_3216Metric_Pad1.30x1.75mm_HandSolder
U9: TL074; SOIC-14_3.9x8.7mm_P1.27mm

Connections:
+12V: C20.2, C22.1, C25.2, IC1.6 (+Vs), IC2.6 (+Vs), U9.4 (V+); also elsewhere on the board
-12V: C19.1, C23.1, C24.1, IC1.3 (-Vs), IC2.3 (-Vs), U9.11 (V-); also elsewhere on the board
GND: C19.2, C20.1, C22.2, C23.2, C24.2, C25.1, IC1.2 (Y2), IC1.4 (Z), IC1.8 (X2), IC2.2 (Y2), IC2.4 (Z), IC2.8 (X2), R18.1, R24.2, U9.3 (+), U9.5 (+), U9.10 (+), U9.12 (+); also elsewhere on the board
unnamed: C21.2, D5.2 (A), R21.1, R22.2, U9.9 (-)
unnamed: C26.2, D6.2 (A), R27.1, R28.2, U9.6 (-)
unnamed: IC1.5 (W), R21.2
unnamed: IC1.1 (Y1), IC1.7 (X1), R17.2, R18.2
unnamed: IC2.5 (W), R27.2
unnamed: IC2.1 (Y1), IC2.7 (X1), R23.2, R24.1
unnamed: R25.1, R26.2, U9.2 (-)
unnamed: R19.1, R20.2, U9.13 (-)
SR_X1_IN_inverted: R19.2, R22.1, U9.14
SR_X2_IN_inverted: R25.2, R28.1, U9.1
Squareroot_X1_IN: R20.1; also elsewhere on the board
Squareroot_X1_OUT: C21.1, D5.1 (K), R17.1, U9.8; also elsewhere on the board
Squareroot_X2_IN: R26.1; also elsewhere on the board
Squareroot_X2_OUT: C26.1, D6.1 (K), R23.1, U9.7; also elsewhere on the board

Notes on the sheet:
sqrt(X)
Power
Square root X1

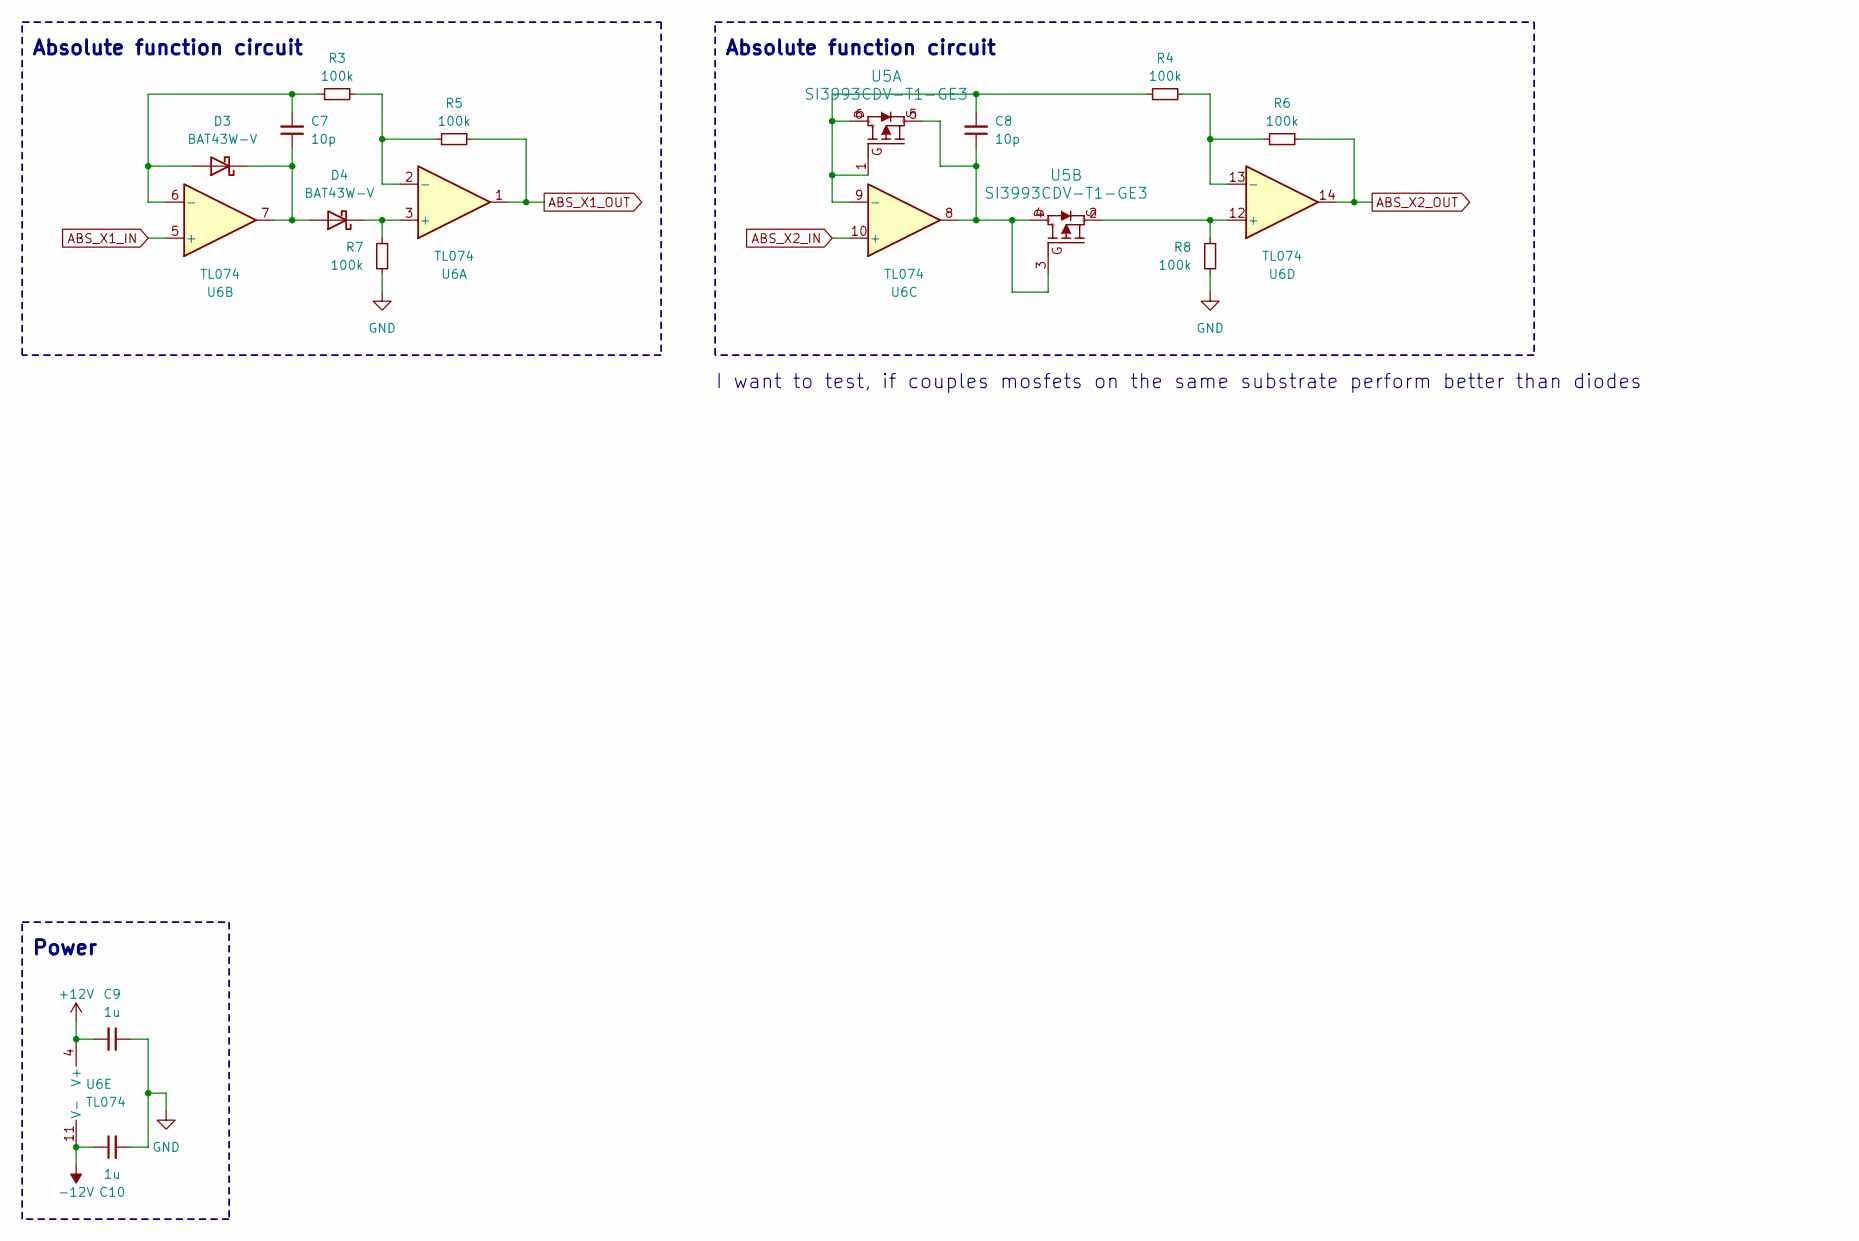
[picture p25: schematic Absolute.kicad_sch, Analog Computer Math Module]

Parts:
C7, C8: 10p; C_1206_3216Metric_Pad1.33x1.80mm_HandSolder
C9, C10: 1u; C_1206_3216Metric_Pad1.33x1.80mm_HandSolder
D3, D4: BAT43W-V; D_1206_3216Metric_Pad1.42x1.75mm_HandSolder
R3, R4, R5, R6, R7, R8: 100k; R_1206_3216Metric_Pad1.30x1.75mm_HandSolder
U5: SI3993CDV-T1-GE3; TSOT-23-6_HandSoldering
U6: TL074; SOIC-14_3.9x8.7mm_P1.27mm

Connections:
+12V: C9.2, U6.4 (V+); also elsewhere on the board
-12V: C10.1, U6.11 (V-); also elsewhere on the board
ABS_X1_IN: U6.5 (+); also elsewhere on the board
ABS_X1_OUT: R5.2, U6.1; also elsewhere on the board
ABS_X2_IN: U6.10 (+); also elsewhere on the board
ABS_X2_OUT: R6.2, U6.14; also elsewhere on the board
GND: C9.1, C10.2, R7.2, R8.2; also elsewhere on the board
unnamed: C7.2, D3.2 (A), R3.1, U6.6 (-)
unnamed: C7.1, D3.1 (K), D4.2 (A), U6.7
unnamed: D4.1 (K), R7.1, U6.3 (+)
unnamed: C8.2, R4.1, U5.1 (G1), U5.6 (D1), U6.9 (-)
unnamed: C8.1, U5.3 (G2), U5.4 (D2), U5.5 (S1), U6.8
unnamed: R8.1, U5.2 (S2), U6.12 (+)
unnamed: R3.2, R5.1, U6.2 (-)
unnamed: R4.2, R6.1, U6.13 (-)

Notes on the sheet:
Absolute function circuit
Power
I want to test, if couples mosfets on the same substrate perform better than diodes

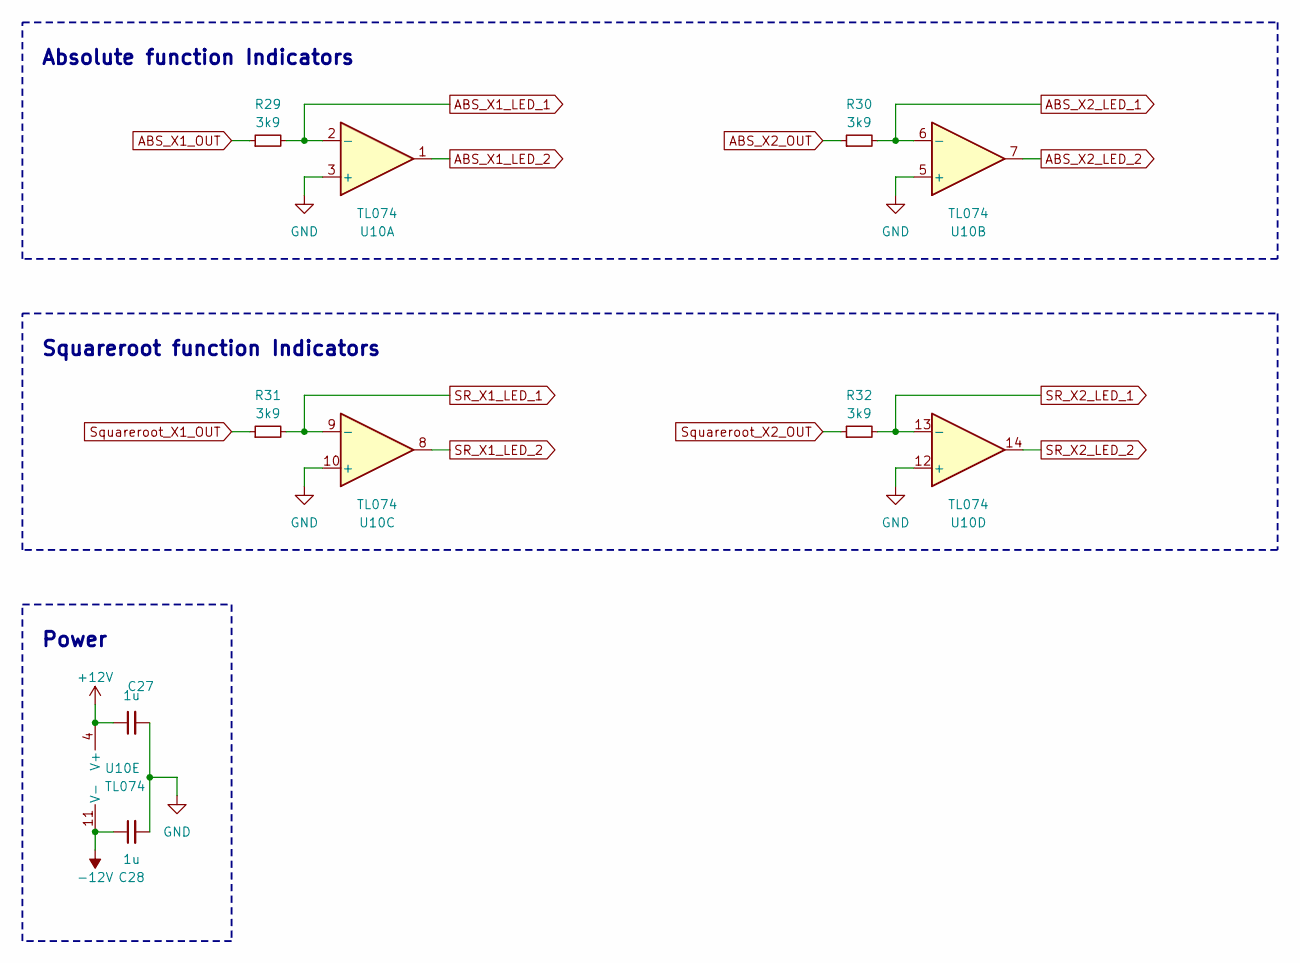
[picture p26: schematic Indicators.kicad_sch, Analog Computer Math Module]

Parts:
C27, C28: 1u; C_1206_3216Metric_Pad1.33x1.80mm_HandSolder
R29, R30, R31, R32: 3k9; R_1206_3216Metric_Pad1.30x1.75mm_HandSolder
U10: TL074; SOIC-14_3.9x8.7mm_P1.27mm

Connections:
+12V: C27.1, U10.4 (V+); also elsewhere on the board
-12V: C28.1, U10.11 (V-); also elsewhere on the board
ABS_X1_LED_1: R29.2, U10.2 (-); also elsewhere on the board
ABS_X1_LED_2: U10.1; also elsewhere on the board
ABS_X1_OUT: R29.1; also elsewhere on the board
ABS_X2_LED_1: R30.2, U10.6 (-); also elsewhere on the board
ABS_X2_LED_2: U10.7; also elsewhere on the board
ABS_X2_OUT: R30.1; also elsewhere on the board
GND: C27.2, C28.2, U10.3 (+), U10.5 (+), U10.10 (+), U10.12 (+); also elsewhere on the board
SR_X1_LED_1: R31.2, U10.9 (-); also elsewhere on the board
SR_X1_LED_2: U10.8; also elsewhere on the board
SR_X2_LED_1: R32.2, U10.13 (-); also elsewhere on the board
SR_X2_LED_2: U10.14; also elsewhere on the board
Squareroot_X1_OUT: R31.1; also elsewhere on the board
Squareroot_X2_OUT: R32.1; also elsewhere on the board

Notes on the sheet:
Squareroot function Indicators
Absolute function Indicators
Power

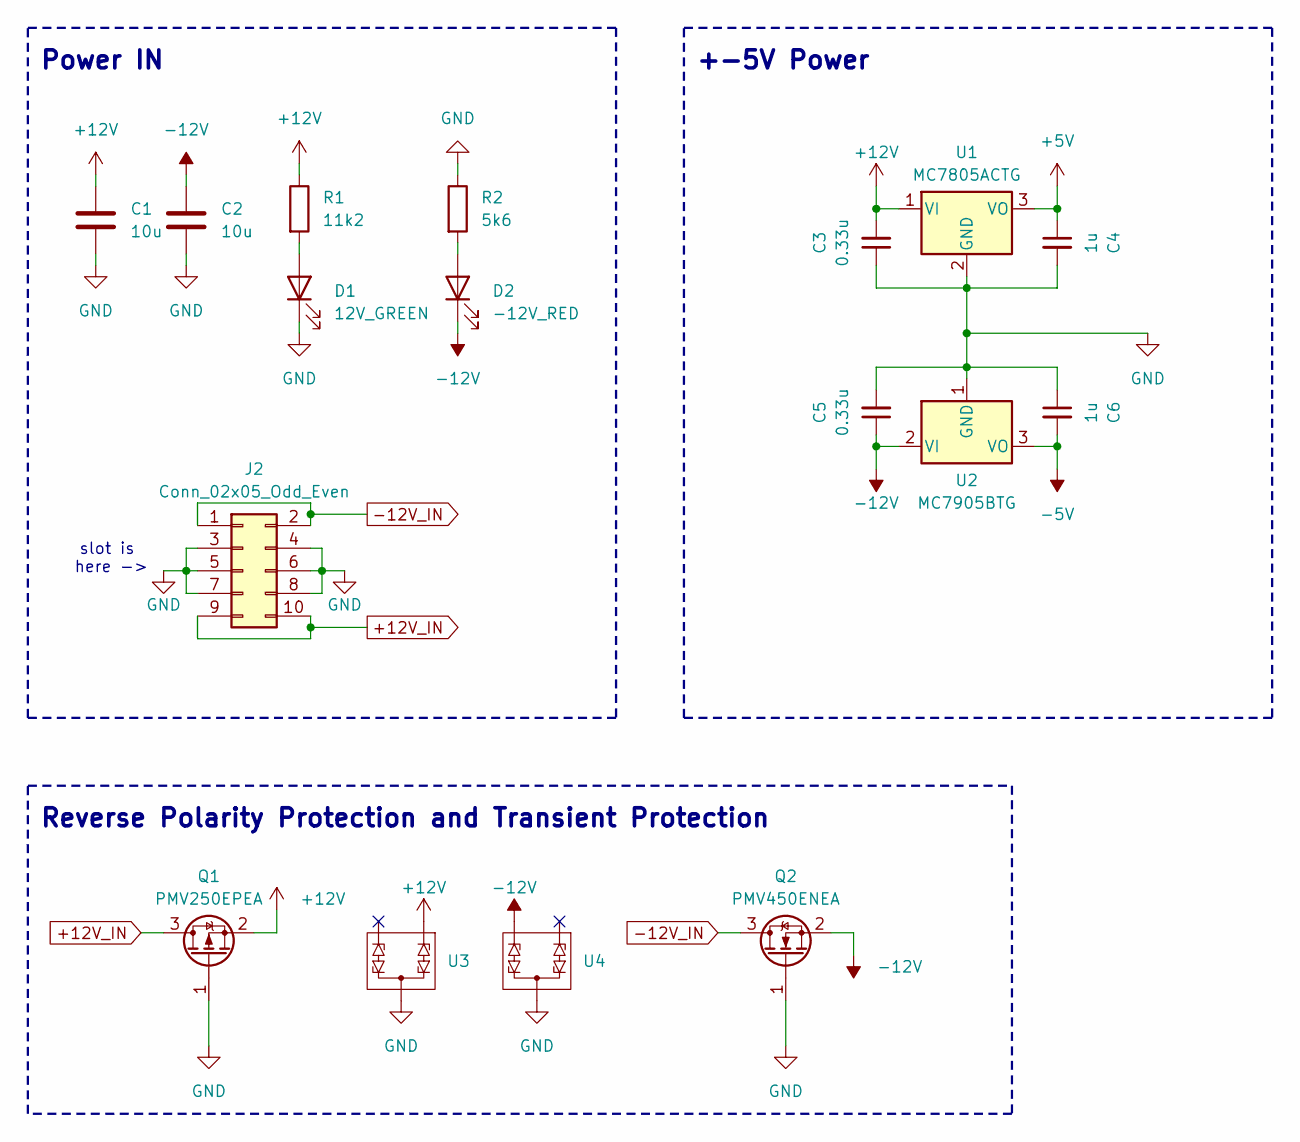
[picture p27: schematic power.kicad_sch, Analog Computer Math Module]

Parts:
C1, C2: 10u; C_1206_3216Metric_Pad1.33x1.80mm_HandSolder
C3, C5: 0.33u; C_1206_3216Metric_Pad1.33x1.80mm_HandSolder
C4, C6: 1u; C_1206_3216Metric_Pad1.33x1.80mm_HandSolder
D1: 12V_GREEN; LED_1206_3216Metric
D2: -12V_RED; LED_1206_3216Metric
J2: Conn_02x05_Odd_Even; PinHeader_2x05_P2.54mm_Vertical
Q1: PMV250EPEA; SOT-23_Handsoldering
Q2: PMV450ENEA; SOT-23_Handsoldering
R1: 11k2; R_1206_3216Metric_Pad1.30x1.75mm_HandSolder
R2: 5k6; R_1206_3216Metric_Pad1.30x1.75mm_HandSolder
U1: MC7805ACTG; TO-220-3_Vertical
U2: MC7905BTG; TO-220-3_Vertical
U3, U4: VCAN16A2; VCAN16A2-03S-E3-08

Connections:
+5V: C4.1, U1.3 (VO); also elsewhere on the board
+12V: C1.1, C3.2, Q1.2 (S), R1.1, U1.1 (VI), U3.1 (IN1); also elsewhere on the board
+12V_IN: J2.9, J2.10, Q1.3 (D)
-5V: C6.2, U2.3 (VO); also elsewhere on the board
-12V: C2.1, C5.1, D2.1 (K), Q2.2 (S), U2.2 (VI), U4.2 (IN2); also elsewhere on the board
-12V_IN: J2.1, J2.2, Q2.3 (D)
GND: C1.2, C2.2, C3.1, C4.2, C5.2, C6.1, D1.1 (K), J2.3, J2.4, J2.5, J2.6, J2.7, J2.8, Q1.1 (G), Q2.1 (G), R2.1, U1.2 (GND), U2.1 (GND), U3.3 (OUT), U4.3 (OUT); also elsewhere on the board
unnamed: D1.2 (A), R1.2
unnamed: D2.2 (A), R2.2

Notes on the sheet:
Reverse Polarity Protection and Transient Protection
Power IN
slot is here ->
+-5V Power

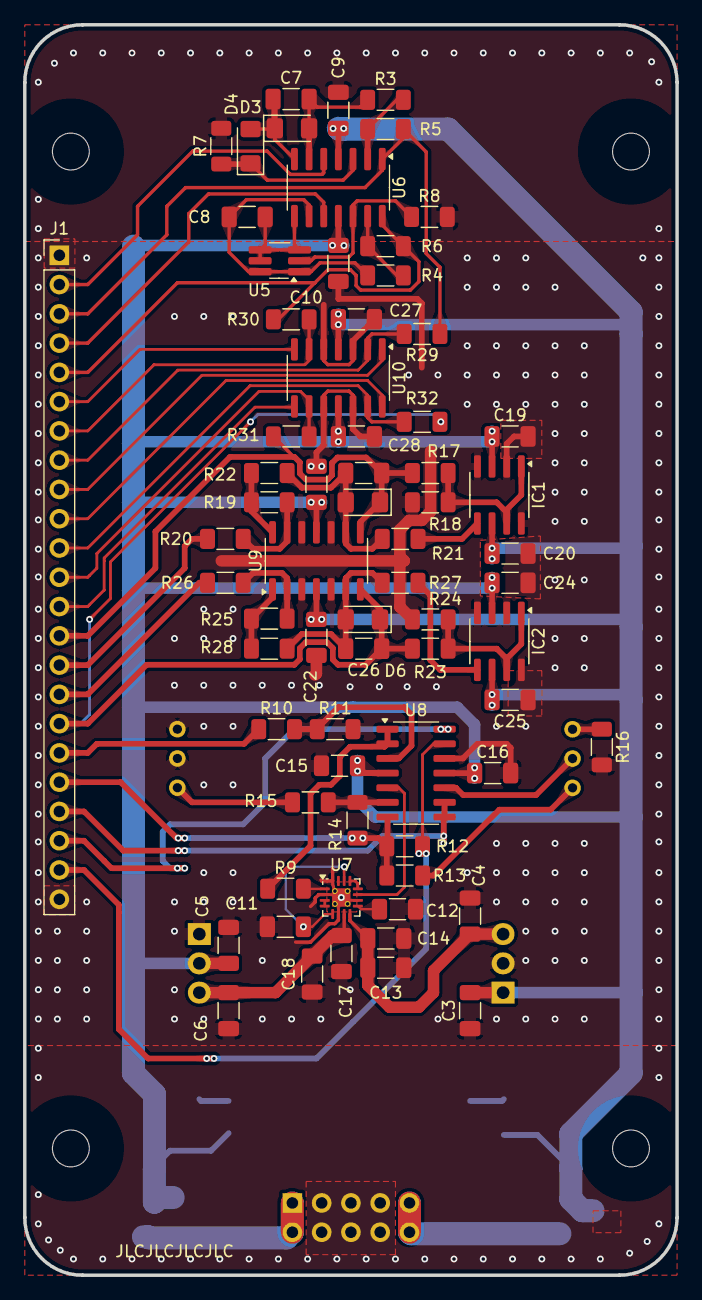
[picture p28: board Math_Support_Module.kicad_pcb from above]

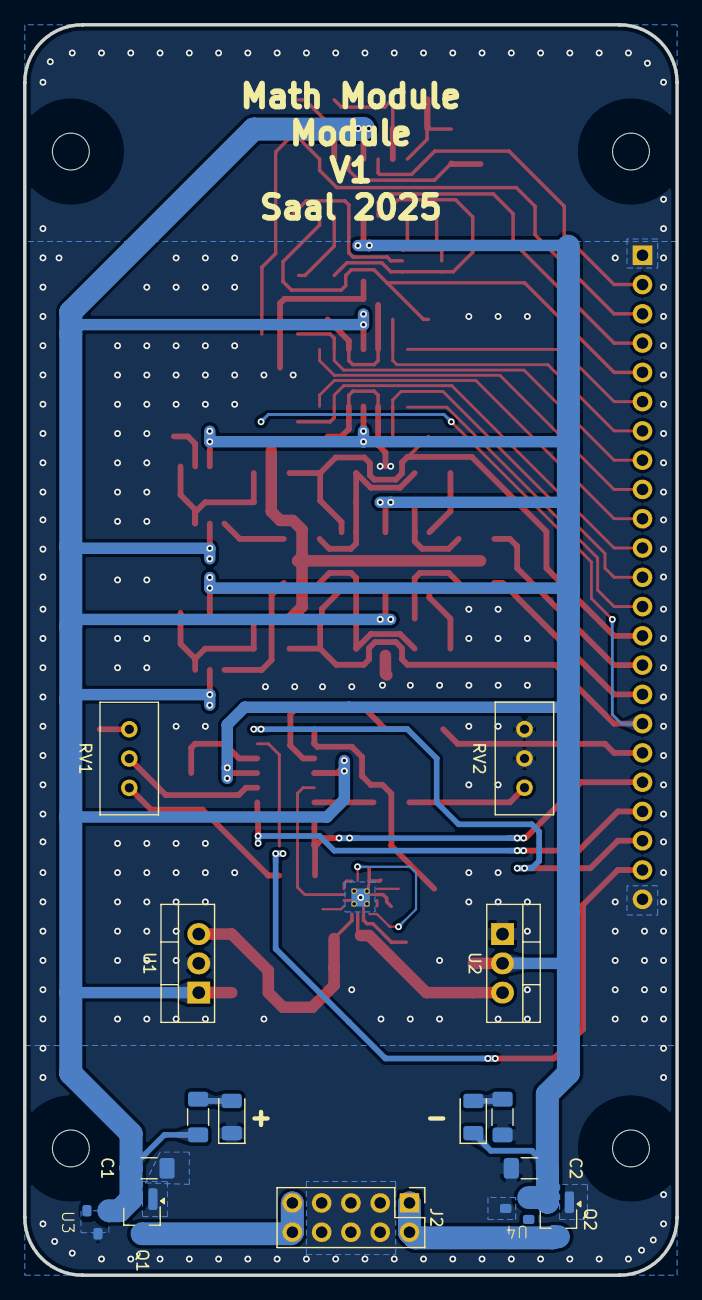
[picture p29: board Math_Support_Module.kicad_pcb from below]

Board: 2 copper layers, 56.6 x 108.5 mm, 88 parts (15 on the bottom side), 61 nets.

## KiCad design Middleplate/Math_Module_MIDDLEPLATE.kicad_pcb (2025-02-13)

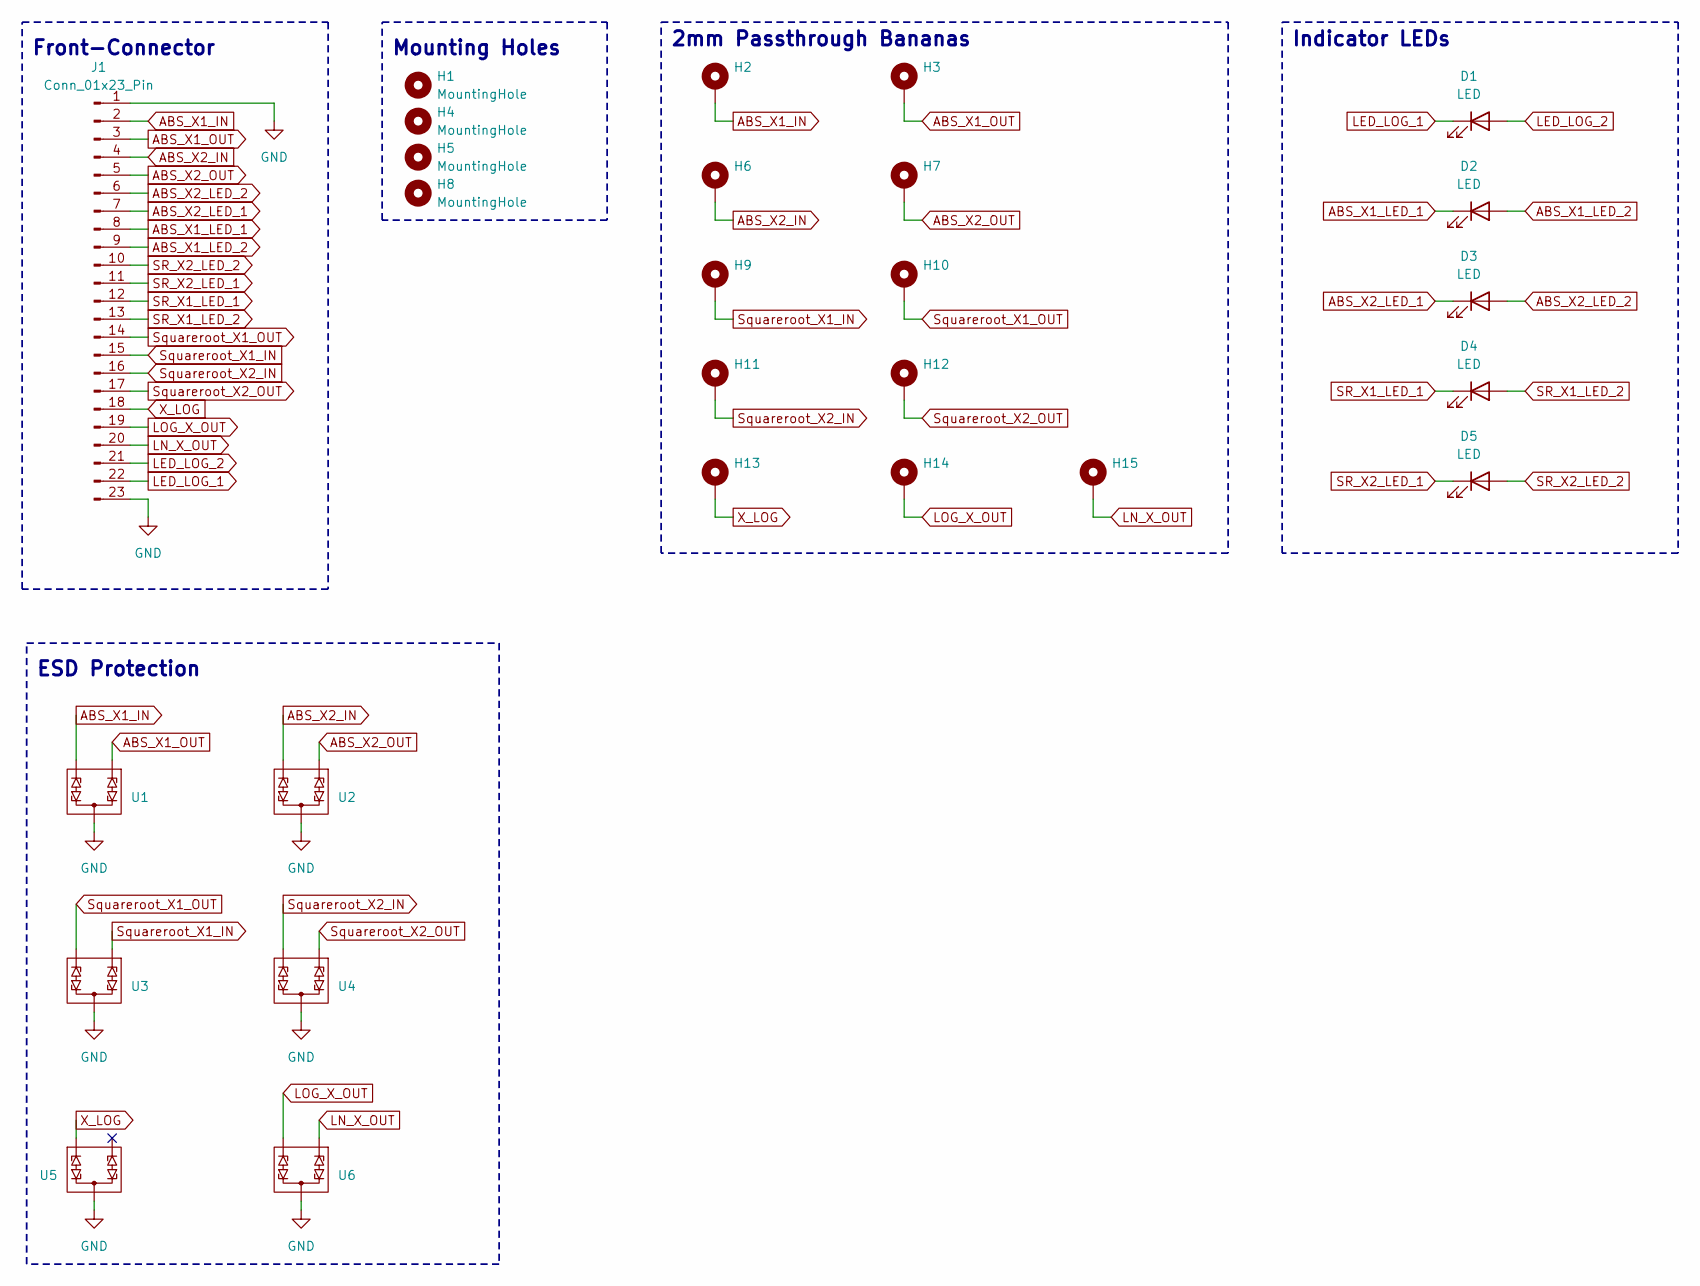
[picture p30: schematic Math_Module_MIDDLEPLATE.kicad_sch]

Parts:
D1, D2, D3, D4, D5: LED; LED_D3.0mm_FlatTop
H1, H4, H5, H8: MountingHole; MountingHole_3.2mm_M3_DIN965
H2: ABS_X1_IN; MountingHole_4.3mm_M4_DIN965_Pad
H3: ABS_X1_OUT; MountingHole_4.3mm_M4_DIN965_Pad
H6: ABS_X2_IN; MountingHole_4.3mm_M4_DIN965_Pad
H7: ABS_X2_OUT; MountingHole_4.3mm_M4_DIN965_Pad
H9: Squareroot_X1_IN; MountingHole_4.3mm_M4_DIN965_Pad
H10: Squareroot_X1_OUT; MountingHole_4.3mm_M4_DIN965_Pad
H11: Squareroot_X2_IN; MountingHole_4.3mm_M4_DIN965_Pad
H12: Squareroot_X2_OUT; MountingHole_4.3mm_M4_DIN965_Pad
H13: X_LOG_IN; MountingHole_4.3mm_M4_DIN965_Pad
H14: LOG_X_OUT; MountingHole_4.3mm_M4_DIN965_Pad
H15: LN_X_OUT; MountingHole_4.3mm_M4_DIN965_Pad
J1: Conn_01x23_Pin; PinSocket_1x23_P2.54mm_Vertical
U1, U2, U3, U4, U5, U6: VCAN16A2; VCAN16A2-03S-E3-08

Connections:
ABS_X1_IN: H2.1, J1.2, U1.2 (IN2)
ABS_X1_LED_1: D2.1 (K), J1.8
ABS_X1_LED_2: D2.2 (A), J1.9
ABS_X1_OUT: H3.1, J1.3, U1.1 (IN1)
ABS_X2_IN: H6.1, J1.4, U2.2 (IN2)
ABS_X2_LED_1: D3.1 (K), J1.7
ABS_X2_LED_2: D3.2 (A), J1.6
ABS_X2_OUT: H7.1, J1.5, U2.1 (IN1)
GND: J1.1, J1.23, U1.3 (OUT), U2.3 (OUT), U3.3 (OUT), U4.3 (OUT), U5.3 (OUT), U6.3 (OUT)
LED_LOG_1: D1.1 (K), J1.22
LED_LOG_2: D1.2 (A), J1.21
LN_X_OUT: H15.1, J1.20, U6.1 (IN1)
LOG_X_OUT: H14.1, J1.19, U6.2 (IN2)
SR_X1_LED_1: D4.1 (K), J1.12
SR_X1_LED_2: D4.2 (A), J1.13
SR_X2_LED_1: D5.1 (K), J1.11
SR_X2_LED_2: D5.2 (A), J1.10
Squareroot_X1_IN: H9.1, J1.15, U3.1 (IN1)
Squareroot_X1_OUT: H10.1, J1.14, U3.2 (IN2)
Squareroot_X2_IN: H11.1, J1.16, U4.2 (IN2)
Squareroot_X2_OUT: H12.1, J1.17, U4.1 (IN1)
X_LOG: H13.1, J1.18, U5.1 (IN1)

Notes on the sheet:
2mm Passthrough Bananas
Front-Connector
ESD Protection
Indicator LEDs
Mounting Holes

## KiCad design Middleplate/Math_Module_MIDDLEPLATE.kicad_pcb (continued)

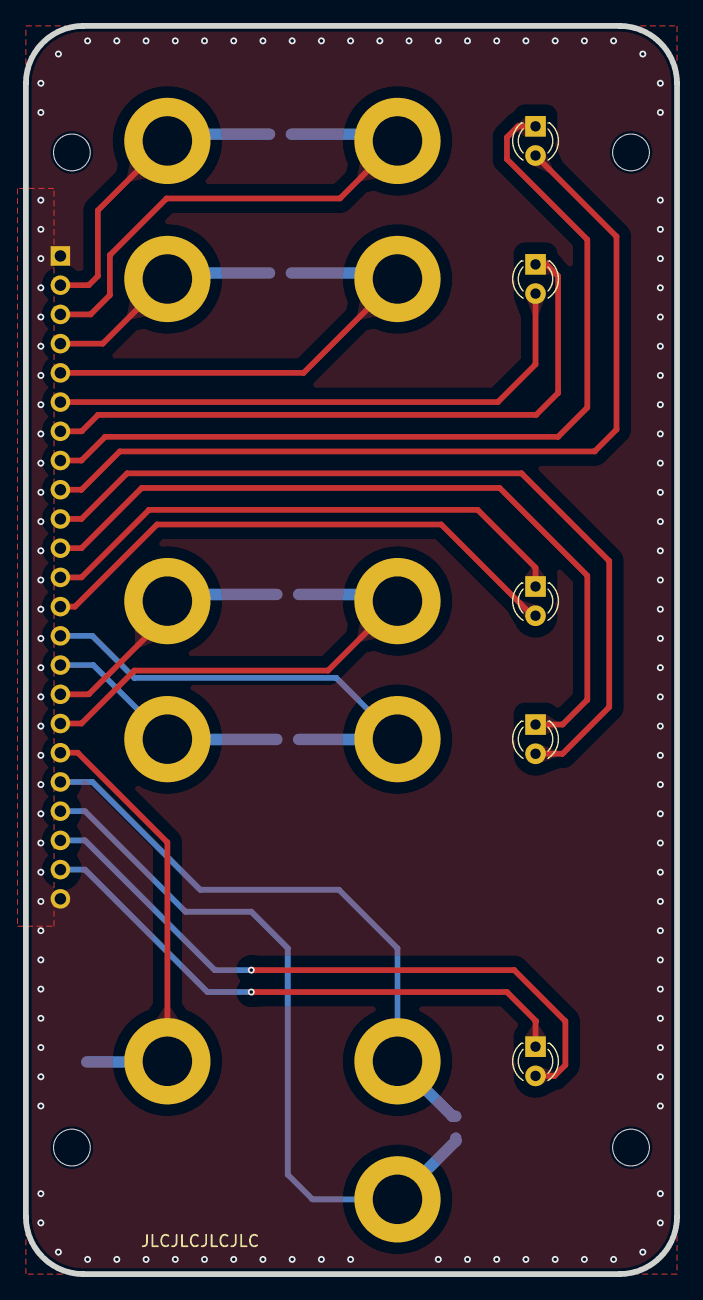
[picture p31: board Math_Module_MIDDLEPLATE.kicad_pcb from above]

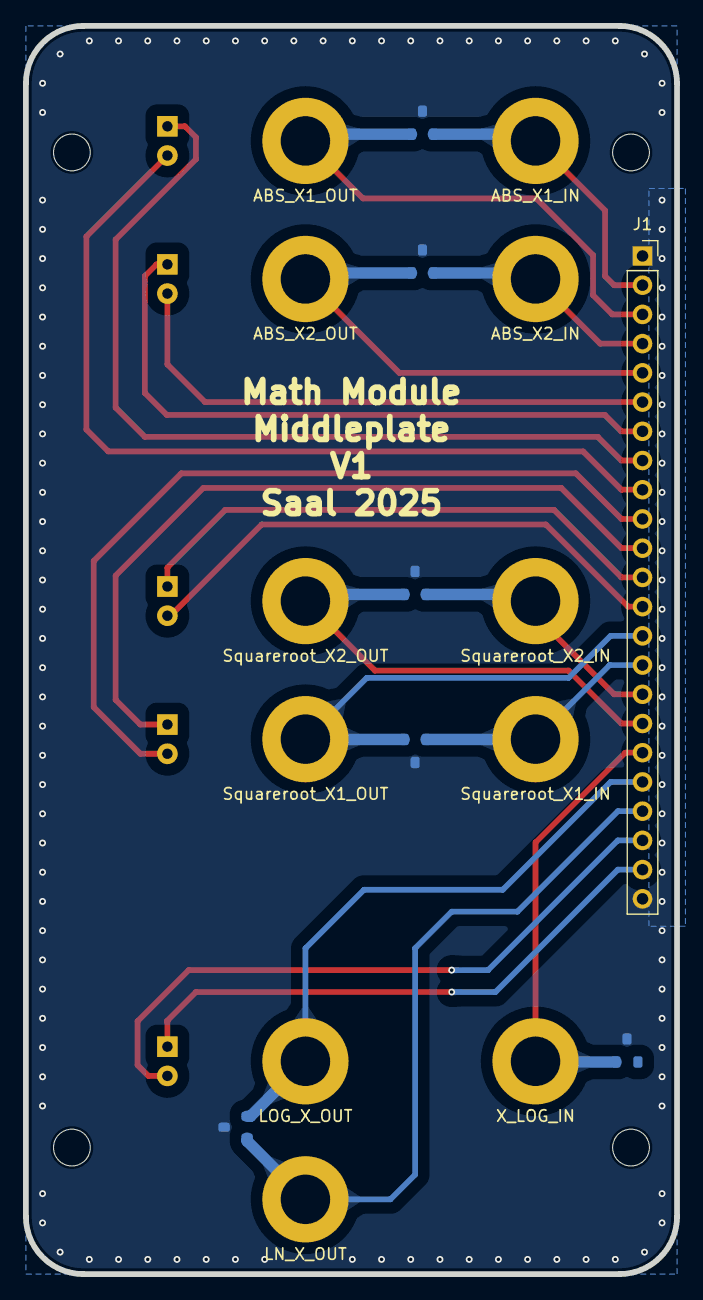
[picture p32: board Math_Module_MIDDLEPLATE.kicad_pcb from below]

Board: 2 copper layers, 56.6 x 108.5 mm, 27 parts (18 on the bottom side), 22 nets.
